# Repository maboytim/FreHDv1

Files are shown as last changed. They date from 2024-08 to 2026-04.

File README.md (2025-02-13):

# TRS-HARD disk emulator, aka 'FreHD'

This is a fork of the original FreHD project by Frederic Vecoven.  The original FreHD project can be found on Frederic's site [https://www.vecoven.com/trs80/trs80.html](https://www.vecoven.com/trs80/trs80.html).  The project has since been moved to github at [https://github.com/veco/FreHDv1](https://github.com/veco/FreHDv1) where the latest versions of everything can be found.

The FreHD emulates both the harddisk controller and the disk storage, plus adds many feature which enhance usability.  The FreHD emulates the original TRS-80 harddisk systems such that the original DOS's that supported hardisks should also work with the FreHD using their original harddisk drivers.

The FreHD consists of several components and the scope of the project is really quite amazing.  First there is hardware itself, which uses a PIC microcontroller for a majority of the function, an SD card for the actual storage, a PAL (programmable logic) for miscellaneous logic, and an RTC (realtime clock).  Software (firmware) embedded in the PIC emulates the harddrive and the additional features and provides access to the RTC.  The main purpose of this fork is to provide compatible alternative firmwares, although it goes a bit beyond that.  Although the intent isn't to improve the original project, some improvements and bugfixes have been provided back to the original project.

The equivalent of everything in the original project is included here but might be modified or improved.     My goal is to maintain as much similarity as possible to the original project including the directory structure.  The directory structure is as follows:

+ hw : Hardware files.
  - gal : Equations of the GAL and the compiled jedec file.
  - protel99 : PCB source (schematics and pcb), in Protel99 format for the original PCB design.  Since it is unlikely that anyone is using Protel99 nowadays this is unlikely to change.
  - kicad : PCB source (schematics and pcb), in KiCad format.  This was converted from the original Protel99 design using a conversion script.  It has since been slightly modified and is subject to change.

+ sw : Software files.
  - pic : PIC MPLAB/MPLABX project files, source code, and compiled hex code.
    - trs_hard : 
    - FatFS  : elm FatFS library, ported to PIC18

+ sw/z80
  - fredhd_rom : source code of the boot menu
  - fredhd_rom/rom-patches : patches for all TRS80 models
  - utils : FreHD utilities

To build the PIC software, you will need Microchip C18 compiler (free)
and MPLab (I used version 8.36). You will also need perl, which is
used to compute the CRC16 used by the bootloader. (If you modify the
source, you need to compile twice, the second time to include the
correct CRC in your hex file).

To build the Z80 code, you need zmac. We are using version 1.3, this
assembler is public domain (by Bruce Norskog and others).

To build the rom patches, you need 'asl'. It is available at:
http://john.ccac.rwth-aachen.de:8000/as/

This project started during the long evenings of December 2012, and I
am very proud to release it to the community today, May 12th 2013. 
Many thanks to Andrew Quinn, who beta-tested and motivated me to
finish this project, or at least make it usable :)

One last thing : you may modify, duplicate, enhance or do whatever you
want with the code. All I ask is to keep this README file. You must
make your modifications available (GPL). If you decide to build and
sell (modified) emulators, all I ask is an emulator for my TRS80, so I
can test your changes.

Enjoy !

-Frederic Vecoven (frederic@vecoven.com)

Last update: Thu Jan 23 15:19:26 2014

!!! github !!!
The code is now available on github. I don't have time to
update/polish the code, so contributions are very welcome.

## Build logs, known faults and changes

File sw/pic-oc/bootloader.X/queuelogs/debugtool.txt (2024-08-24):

2493 1724344660412 GEN4_TO_CONTROLLER_LOG:GEN4_DEBUG_INT_LOG_PIC18F47Q83 Pre:DebugReadTargetMemory
2493 1724344660412 GEN4_TO_CONTROLLER_LOG:GEN4_DEBUG_INT_LOG_PIC18F47Q83 Payload
2493 1724344660412 GEN4_TO_CONTROLLER_LOG:GEN4_DEBUG_INT_LOG_PIC18F47Q83 FileRegs
2493 1724344660412 GEN4_TO_CONTROLLER_LOG:GEN4_DEBUG_INT_LOG_PIC18F47Q83 4d8
2493 1724344660412 GEN4_TO_CONTROLLER_LOG:GEN4_DEBUG_INT_LOG_PIC18F47Q83 4d8
2493 1724344660412 GEN4_TO_CONTROLLER_LOG:GEN4_DEBUG_INT_LOG_PIC18F47Q83 Length = 1
2493 1724344660412 GEN4_TO_CONTROLLER_LOG:GEN4_DEBUG_INT_LOG_PIC18F47Q83 Payload End
2493 1724344660412 XXXX 1724344660412, Thread 2493: XXXX 1724344660412, Entering Thread 2493: Commands::runScriptWithUpload, script name = ReadRAM  
2493 1724344660413 XXXX 1724344660413, Thread 2493: XXXX 1724344660413, Entering Thread 2493: ToolCommUsb::readTransfer, sideData is 0x25 bytes long, transferDataLength is 0x1 bytes long  
2493 1724344660415 XXXX 1724344660415, Thread 2493: com.Send returned false 
2493 1724344660415 XXXX 1724344660415, Thread 2493: readTransfer: exception after writeHeaderAndGetAck null 
2493 1724344660415 XXXX 1724344660415, Thread 2493: XXXX 1724344660415, Entering Thread 2493: ToolCommUsb::recoverFromProtocolError, type = NO_SCRIPT  
2493 1724344660415 XXXX 1724344660415, Thread 2493: Send Abort Script Engine Command 
2493 1724344660415 XXXX 1724344660415, Thread 2493: XXXX 1724344660415, Entering Thread 2493: ToolCommUsb::killScriptEngine  
2493 1724344660417 XXXX 1724344660417, Thread 2493: com.Send returned false 
2493 1724344660417 XXXX 1724344660417, Thread 2493: Failed sending Abort Script Engine Command. Set nuclear option = true 
2493 1724344660417 XXXX 1724344660417, Thread 2493: About to nuke 
2493 1724344660417 XXXX 1724344660417, Thread 2493: XXXX 1724344660417, Entering Thread 2493: ToolCommUsb::nuclearOption  
2493 1724344660419 XXXX 1724344660419, Thread 2493: com.Send returned false

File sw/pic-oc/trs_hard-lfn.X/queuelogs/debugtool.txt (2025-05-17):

2483 1747105636176 GEN4_CONNECT_DIAGNOSTICS:MPLABCommTool is null

2483 1747105636176 GEN4_TO_CONTROLLER_LOG:GEN4_CONNECT_INT_LOG_PIC18F47Q83 Pre:GetFirmwareInfo
2483 1747105636176 GEN4_TO_CONTROLLER_LOG:GEN4_CONNECT_INT_LOG_PIC18F47Q83 Payload
2483 1747105636176 GEN4_TO_CONTROLLER_LOG:GEN4_CONNECT_INT_LOG_PIC18F47Q83 null
2483 1747105636176 GEN4_TO_CONTROLLER_LOG:GEN4_CONNECT_INT_LOG_PIC18F47Q83 Payload End
2483 1747105636177 XXXX 1747105636177, Thread 2483: com.Send returned false 
2483 1747105636177 XXXX 1747105636177, Thread 2483: execCommand: exception after writeSideChanel null 
2483 1747105636177 GEN4_CONNECT_DIAGNOSTICS:Removing plug and play observer com.microchip.mplab.mdbcore.RI4Tool.RI4ToolBase$RI4PlugNPlayObserver@bf5e00b
2483 1747105636177 GEN4_CONNECT_DIAGNOSTICS:Begin PlugNPlayObservers list dump:
2483 1747105636177 GEN4_CONNECT_DIAGNOSTICS:End PlugNPlayObservers list dump:
2483 1747105636228 GEN4_CONNECT_DIAGNOSTICS:Calling RIDbgToolCom.Disconnect
2483 1747105636228 GEN4_CONNECT_DIAGNOSTICS:Calling MPLABCommTool.Detach to remove tool from plug and play list
2483 1747105636228 GEN4_CONNECT_DIAGNOSTICS:Calling RIDbgToolCom.DisconnectFromMPlabComm
2483 1747105636228 GEN4_CONNECT_DIAGNOSTICS:Calling MPLABCommTool.Disconnect
2491 1747105745831 GEN4_CONNECT_DIAGNOSTICS:MPLABCommTool is NOT null
2491 1747105745831 GEN4_CONNECT_DIAGNOSTICS:AttachedToolPID = 9036, AttachedToolVID = 4d8
2491 1747105745831 GEN4_CONNECT_DIAGNOSTICS:transport type = USB
2491 1747105745831 GEN4_CONNECT_DIAGNOSTICS:AttachedToolPID = 9036, AttachedToolVID = 4d8
2491 1747105745834 com.microchip.mplab.mdbcore.RealICETool.RIDbgToolCom
2491 1747105745834 GEN4_CONNECT_DIAGNOSTICS:Before MPLABCommTool.Connect()
2491 1747105745834 GEN4_CONNECT_DIAGNOSTICS:After MPLABCommTool.Connect()
2491 1747105745834 GEN4_CONNECT_DIAGNOSTICS:Adding new plug and play observer com.microchip.mplab.mdbcore.RI4Tool.RI4ToolBase$RI4PlugNPlayObserver@5f161bb
2491 1747105745834 GEN4_CONNECT_DIAGNOSTICS:Begin PlugNPlayObservers list dump:
2491 1747105745834 GEN4_CONNECT_DIAGNOSTICS:com.microchip.mplab.mdbcore.RI4Tool.RI4ToolBase$RI4PlugNPlayObserver@5f161bb
2491 1747105745834 GEN4_CONNECT_DIAGNOSTICS:End PlugNPlayObservers list dump:
2491 1747105745834 GEN4_CONNECT_DIAGNOSTICS:Registering for alternate PNP notifications. CommPnPCriteria.cPIDList = [9035], CommPnPCriteria.cSerialNumber = 020026702ryn015334

2491 1747105745893 GEN4_TO_CONTROLLER_LOG:GEN4_INIT_INT_LOG_PIC18F47Q83 Pre:init
2491 1747105745893 GEN4_TO_CONTROLLER_LOG:GEN4_INIT_INT_LOG_PIC18F47Q83 Payload
2491 1747105745893 GEN4_TO_CONTROLLER_LOG:GEN4_INIT_INT_LOG_PIC18F47Q83 DeviceInfo: Values:
2491 1747105745893 GEN4_TO_CONTROLLER_LOG:GEN4_INIT_INT_LOG_PIC18F47Q83 DeviceInfo: pcAddress = 000004f9, Vpp = 9.00, useRowEraseIfVoltageIsLow = true, voltageBelowWhichUseRowErase = 2.10, deviceName = PIC18F47Q83, programmerType = PIC18ENH_V2
2491 1747105745893 GEN4_TO_CONTROLLER_LOG:GEN4_INIT_INT_LOG_PIC18F47Q83 DeviceInfo: MemInfo values:
2491 1747105745893 GEN4_TO_CONTROLLER_LOG:GEN4_INIT_INT_LOG_PIC18F47Q83 DeviceInfo: mask = ffff, exists = true, startAddr = 00000000, endAddr = 0001ffff, rowSize = 0080, rowEraseSize = 0080, addrInc = 0002, widthProgram = 0002
2491 1747105745893 GEN4_TO_CONTROLLER_LOG:GEN4_INIT_INT_LOG_PIC18F47Q83 DeviceInfo: mask = 00ff, exists = true, startAddr = 00300000, endAddr = 00300023, rowSize = 0001, rowEraseSize = 0000, addrInc = 0001, widthProgram = 0001
2491 1747105745893 GEN4_TO_CONTROLLER_LOG:GEN4_INIT_INT_LOG_PIC18F47Q83 DeviceInfo: mask = 0000, exists = false, startAddr = 00000000, endAddr = 00000000, rowSize = 0000, rowEraseSize = 0000, addrInc = 0000, widthProgram = 0000
2491 1747105745893 GEN4_TO_CONTROLLER_LOG:GEN4_INIT_INT_LOG_PIC18F47Q83 DeviceInfo: mask = 00ff, exists = true, startAddr = 00380000, endAddr = 003803ff, rowSize = 0001, rowEraseSize = 0000, addrInc = 0001, widthProgram = 0001
2491 1747105745893 GEN4_TO_CONTROLLER_LOG:GEN4_INIT_INT_LOG_PIC18F47Q83 DeviceInfo: mask = ffff, exists = true, startAddr = 00200000, endAddr = 0020003f, rowSize = 0001, rowEraseSize = 0000, addrInc = 0002, widthProgram = 0002
2491 1747105745893 GEN4_TO_CONTROLLER_LOG:GEN4_INIT_INT_LOG_PIC18F47Q83 DeviceInfo: mask = ffff, exists = true, startAddr = 00200000, endAddr = 002403ff, rowSize = 0080, rowEraseSize = 0080, addrInc = 0002, widthProgram = 0002
2491 1747105745893 GEN4_TO_CONTROLLER_LOG:GEN4_INIT_INT_LOG_PIC18F47Q83 DeviceInfo: mask = 0000, exists = false, startAddr = 00000000, endAddr = 00000000, rowSize = 0000, rowEraseSize = 0000, addrInc = 0001, widthProgram = 0001
2491 1747105745893 GEN4_TO_CONTROLLER_LOG:GEN4_INIT_INT_LOG_PIC18F47Q83 DeviceInfo: mask = 0000, exists = false, startAddr = 00000000, endAddr = 00000000, rowSize = 0000, rowEraseSize = 0000, addrInc = 0000, widthProgram = 0000
2491 1747105745893 GEN4_TO_CONTROLLER_LOG:GEN4_INIT_INT_LOG_PIC18F47Q83 DeviceInfo: mask = 0000, exists = false, startAddr = 00000000, endAddr = 00000000, rowSize = 0000, rowEraseSize = 0000, addrInc = 0000, widthProgram = 0000
2491 1747105745893 GEN4_TO_CONTROLLER_LOG:GEN4_INIT_INT_LOG_PIC18F47Q83 DeviceInfo: mask = 0000, exists = false, startAddr = 00000000, endAddr = 00000000, rowSize = 0000, rowEraseSize = 0000, addrInc = 0000, widthProgram = 0000
2491 1747105745893 GEN4_TO_CONTROLLER_LOG:GEN4_INIT_INT_LOG_PIC18F47Q83 DeviceInfo: mask = 0000, exists = false, startAddr = 00000000, endAddr = 00000000, rowSize = 0000, rowEraseSize = 0000, addrInc = 0001, widthProgram = 0001
2491 1747105745893 GEN4_TO_CONTROLLER_LOG:GEN4_INIT_INT_LOG_PIC18F47Q83 DeviceInfo: mask = 0000, exists = false, startAddr = 00000000, endAddr = 00000000, rowSize = 0000, rowEraseSize = 0000, addrInc = 0001, widthProgram = 0001
2491 1747105745893 GEN4_TO_CONTROLLER_LOG:GEN4_INIT_INT_LOG_PIC18F47Q83 DeviceInfo: mask = 0000, exists = false, startAddr = 00000000, endAddr = 00000000, rowSize = 0000, rowEraseSize = 0000, addrInc = 0000, widthProgram = 0000
2491 1747105745893 GEN4_TO_CONTROLLER_LOG:GEN4_INIT_INT_LOG_PIC18F47Q83 DeviceInfo: mask = 0000, exists = false, startAddr = 00000000, endAddr = 00000000, rowSize = 0000, rowEraseSize = 0000, addrInc = 0000, widthProgram = 0000
2491 1747105745893 GEN4_TO_CONTROLLER_LOG:GEN4_INIT_INT_LOG_PIC18F47Q83 DeviceInfo: mask = 0000, exists = false, startAddr = 00000000, endAddr = 00000000, rowSize = 0000, rowEraseSize = 0000, addrInc = 0000, widthProgram = 0000
2491 1747105745893 GEN4_TO_CONTROLLER_LOG:GEN4_INIT_INT_LOG_PIC18F47Q83 DeviceInfo: mask = 0000, exists = false, startAddr = 00000000, endAddr = 00000000, rowSize = 0000, rowEraseSize = 0000, addrInc = 0000, widthProgram = 0000
2491 1747105745893 GEN4_TO_CONTROLLER_LOG:GEN4_INIT_INT_LOG_PIC18F47Q83 DeviceInfo: mask = 7fffffff, exists = true, startAddr = 003ffffe, endAddr = 003fffff, rowSize = 0001, rowEraseSize = 0000, addrInc = 0001, widthProgram = 0001
2491 1747105745893 GEN4_TO_CONTROLLER_LOG:GEN4_INIT_INT_LOG_PIC18F47Q83 DeviceInfo: mask = 0000, exists = false, startAddr = 00000000, endAddr = 00000000, rowSize = 0000, rowEraseSize = 0000, addrInc = 0000, widthProgram = 0000
2491 1747105745893 GEN4_TO_CONTROLLER_LOG:GEN4_INIT_INT_LOG_PIC18F47Q83 DeviceInfo: mask = ffff, exists = true, startAddr = 003c0000, endAddr = 003c000f, rowSize = 0080, rowEraseSize = 0000, addrInc = 0002, widthProgram = 0002
2491 1747105745893 GEN4_TO_CONTROLLER_LOG:GEN4_INIT_INT_LOG_PIC18F47Q83 DeviceInfo: mask = ffff, exists = true, startAddr = 002c0000, endAddr = 002c003f, rowSize = 0080, rowEraseSize = 0000, addrInc = 0002, widthProgram = 0002
2491 1747105745893 GEN4_TO_CONTROLLER_LOG:GEN4_INIT_INT_LOG_PIC18F47Q83 DeviceInfo: mask = 0000, exists = false, startAddr = 00000000, endAddr = 00000000, rowSize = 0000, rowEraseSize = 0000, addrInc = 0000, widthProgram = 0000
2491 1747105745893 GEN4_TO_CONTROLLER_LOG:GEN4_INIT_INT_LOG_PIC18F47Q83 DeviceInfo: mask = 0000, exists = false, startAddr = 00000000, endAddr = 00000000, rowSize = 0000, rowEraseSize = 0000, addrInc = 0000, widthProgram = 0000
2491 1747105745893 GEN4_TO_CONTROLLER_LOG:GEN4_INIT_INT_LOG_PIC18F47Q83 DeviceInfo: mask = 0000, exists = false, startAddr = 00000000, endAddr = 00000000, rowSize = 0000, rowEraseSize = 0000, addrInc = 0000, widthProgram = 0000
2491 1747105745893 GEN4_TO_CONTROLLER_LOG:GEN4_INIT_INT_LOG_PIC18F47Q83 DeviceInfo: CfgRequiredBitsMask Values:
2491 1747105745893 GEN4_TO_CONTROLLER_LOG:GEN4_INIT_INT_LOG_PIC18F47Q83 Address = 00300000, Mask = 00000077
2491 1747105745893 GEN4_TO_CONTROLLER_LOG:GEN4_INIT_INT_LOG_PIC18F47Q83 Address = 00300001, Mask = 0000002b
2491 1747105745893 GEN4_TO_CONTROLLER_LOG:GEN4_INIT_INT_LOG_PIC18F47Q83 Address = 00300002, Mask = 000000ff
2491 1747105745893 GEN4_TO_CONTROLLER_LOG:GEN4_INIT_INT_LOG_PIC18F47Q83 Address = 00300003, Mask = 000000bf
2491 1747105745893 GEN4_TO_CONTROLLER_LOG:GEN4_INIT_INT_LOG_PIC18F47Q83 Address = 00300004, Mask = 0000007f
2491 1747105745893 GEN4_TO_CONTROLLER_LOG:GEN4_INIT_INT_LOG_PIC18F47Q83 Address = 00300005, Mask = 0000003f
2491 1747105745893 GEN4_TO_CONTROLLER_LOG:GEN4_INIT_INT_LOG_PIC18F47Q83 Address = 00300006, Mask = 0000001f
2491 1747105745893 GEN4_TO_CONTROLLER_LOG:GEN4_INIT_INT_LOG_PIC18F47Q83 Address = 00300007, Mask = 0000008f
2491 1747105745893 GEN4_TO_CONTROLLER_LOG:GEN4_INIT_INT_LOG_PIC18F47Q83 Address = 00300008, Mask = 00000033
2491 1747105745893 GEN4_TO_CONTROLLER_LOG:GEN4_INIT_INT_LOG_PIC18F47Q83 Address = 00300009, Mask = 00000001
2491 1747105745893 GEN4_TO_CONTROLLER_LOG:GEN4_INIT_INT_LOG_PIC18F47Q83 Address = 0030000a, Mask = 000000ff
2491 1747105745893 GEN4_TO_CONTROLLER_LOG:GEN4_INIT_INT_LOG_PIC18F47Q83 Address = 0030000b, Mask = 000000ff
2491 1747105745893 GEN4_TO_CONTROLLER_LOG:GEN4_INIT_INT_LOG_PIC18F47Q83 Address = 0030000c, Mask = 000000ff
2491 1747105745893 GEN4_TO_CONTROLLER_LOG:GEN4_INIT_INT_LOG_PIC18F47Q83 Address = 0030000d, Mask = 000000ff
2491 1747105745893 GEN4_TO_CONTROLLER_LOG:GEN4_INIT_INT_LOG_PIC18F47Q83 Address = 0030000e, Mask = 000000ff
2491 1747105745893 GEN4_TO_CONTROLLER_LOG:GEN4_INIT_INT_LOG_PIC18F47Q83 Address = 0030000f, Mask = 000000ff
2491 1747105745893 GEN4_TO_CONTROLLER_LOG:GEN4_INIT_INT_LOG_PIC18F47Q83 Address = 00300010, Mask = 000000ff
2491 1747105745893 GEN4_TO_CONTROLLER_LOG:GEN4_INIT_INT_LOG_PIC18F47Q83 Address = 00300011, Mask = 000000ff
2491 1747105745893 GEN4_TO_CONTROLLER_LOG:GEN4_INIT_INT_LOG_PIC18F47Q83 Address = 00300012, Mask = 000000ff
2491 1747105745893 GEN4_TO_CONTROLLER_LOG:GEN4_INIT_INT_LOG_PIC18F47Q83 Address = 00300013, Mask = 000000ff
2491 1747105745893 GEN4_TO_CONTROLLER_LOG:GEN4_INIT_INT_LOG_PIC18F47Q83 Address = 00300014, Mask = 000000ff
2491 1747105745893 GEN4_TO_CONTROLLER_LOG:GEN4_INIT_INT_LOG_PIC18F47Q83 Address = 00300015, Mask = 000000ff
2491 1747105745893 GEN4_TO_CONTROLLER_LOG:GEN4_INIT_INT_LOG_PIC18F47Q83 Address = 00300016, Mask = 000000ff
2491 1747105745893 GEN4_TO_CONTROLLER_LOG:GEN4_INIT_INT_LOG_PIC18F47Q83 Address = 00300017, Mask = 000000ff
2491 1747105745893 GEN4_TO_CONTROLLER_LOG:GEN4_INIT_INT_LOG_PIC18F47Q83 Address = 00300018, Mask = 000000ff
2491 1747105745893 GEN4_TO_CONTROLLER_LOG:GEN4_INIT_INT_LOG_PIC18F47Q83 Address = 00300019, Mask = 000000ff
2491 1747105745893 GEN4_TO_CONTROLLER_LOG:GEN4_INIT_INT_LOG_PIC18F47Q83 Address = 0030001a, Mask = 000000ff
2491 1747105745893 GEN4_TO_CONTROLLER_LOG:GEN4_INIT_INT_LOG_PIC18F47Q83 Address = 0030001b, Mask = 000000ff
2491 1747105745893 GEN4_TO_CONTROLLER_LOG:GEN4_INIT_INT_LOG_PIC18F47Q83 Address = 0030001c, Mask = 000000ff
2491 1747105745893 GEN4_TO_CONTROLLER_LOG:GEN4_INIT_INT_LOG_PIC18F47Q83 Address = 0030001d, Mask = 000000ff
2491 1747105745893 GEN4_TO_CONTROLLER_LOG:GEN4_INIT_INT_LOG_PIC18F47Q83 Address = 0030001e, Mask = 000000ff
2491 1747105745893 GEN4_TO_CONTROLLER_LOG:GEN4_INIT_INT_LOG_PIC18F47Q83 Address = 0030001f, Mask = 000000ff
2491 1747105745893 GEN4_TO_CONTROLLER_LOG:GEN4_INIT_INT_LOG_PIC18F47Q83 Address = 00300020, Mask = 000000ff
2491 1747105745893 GEN4_TO_CONTROLLER_LOG:GEN4_INIT_INT_LOG_PIC18F47Q83 Address = 00300021, Mask = 000000ff
2491 1747105745893 GEN4_TO_CONTROLLER_LOG:GEN4_INIT_INT_LOG_PIC18F47Q83 Address = 00300022, Mask = 000000ff
2491 1747105745893 GEN4_TO_CONTROLLER_LOG:GEN4_INIT_INT_LOG_PIC18F47Q83 BasicInfo: Values:
2491 1747105745893 GEN4_TO_CONTROLLER_LOG:GEN4_INIT_INT_LOG_PIC18F47Q83 BasicInfo: InputStream = com.microchip.mplab.libs.toolpacksupport.EquatableFileInputStream@cc306916, ToolFlavor = PIC32C
2491 1747105745893 GEN4_TO_CONTROLLER_LOG:GEN4_INIT_INT_LOG_PIC18F47Q83 Payload End
2491 1747105745894 GEN4_TO_CONTROLLER_LOG:GEN4_INIT_INT_LOG_PIC18F47Q83 Post:init
2491 1747105745894 GEN4_TO_CONTROLLER_LOG:GEN4_INIT_INT_LOG_PIC18F47Q83 Return Value
2491 1747105745894 GEN4_TO_CONTROLLER_LOG:GEN4_INIT_INT_LOG_PIC18F47Q83 none
2491 1747105745894 GEN4_TO_CONTROLLER_LOG:GEN4_INIT_INT_LOG_PIC18F47Q83 Return End

2491 1747105745894 GEN4_TO_CONTROLLER_LOG:GEN4_INIT_INT_LOG_PIC18F47Q83 Pre:GetInterfaceProvider
2491 1747105745894 GEN4_TO_CONTROLLER_LOG:GEN4_INIT_INT_LOG_PIC18F47Q83 Payload
2491 1747105745894 GEN4_TO_CONTROLLER_LOG:GEN4_INIT_INT_LOG_PIC18F47Q83 RI4DebugInterface
2491 1747105745894 GEN4_TO_CONTROLLER_LOG:GEN4_INIT_INT_LOG_PIC18F47Q83 Payload End
2491 1747105745894 GEN4_TO_CONTROLLER_LOG:GEN4_INIT_INT_LOG_PIC18F47Q83 Post:GetInterfaceProvider
2491 1747105745894 GEN4_TO_CONTROLLER_LOG:GEN4_INIT_INT_LOG_PIC18F47Q83 Return Value
2491 1747105745894 GEN4_TO_CONTROLLER_LOG:GEN4_INIT_INT_LOG_PIC18F47Q83 com.microchip.mplab.libs.RI4ToolsController.implementations.RI4DebugInterfaceImpl@34bef190
2491 1747105745894 GEN4_TO_CONTROLLER_LOG:GEN4_INIT_INT_LOG_PIC18F47Q83 Return End

2491 1747105745895 GEN4_TO_CONTROLLER_LOG:GEN4_INIT_INT_LOG_PIC18F47Q83 Pre:GetInterfaceProvider
2491 1747105745895 GEN4_TO_CONTROLLER_LOG:GEN4_INIT_INT_LOG_PIC18F47Q83 Payload
2491 1747105745895 GEN4_TO_CONTROLLER_LOG:GEN4_INIT_INT_LOG_PIC18F47Q83 RI4ProgramInterface
2491 1747105745895 GEN4_TO_CONTROLLER_LOG:GEN4_INIT_INT_LOG_PIC18F47Q83 Payload End
2491 1747105745895 GEN4_TO_CONTROLLER_LOG:GEN4_INIT_INT_LOG_PIC18F47Q83 Post:GetInterfaceProvider
2491 1747105745895 GEN4_TO_CONTROLLER_LOG:GEN4_INIT_INT_LOG_PIC18F47Q83 Return Value
2491 1747105745895 GEN4_TO_CONTROLLER_LOG:GEN4_INIT_INT_LOG_PIC18F47Q83 com.microchip.mplab.libs.RI4ToolsController.implementations.RI4ProgramInterfaceImpl@10871a2b
2491 1747105745895 GEN4_TO_CONTROLLER_LOG:GEN4_INIT_INT_LOG_PIC18F47Q83 Return End

2491 1747105745895 GEN4_TO_CONTROLLER_LOG:GEN4_INIT_INT_LOG_PIC18F47Q83 Pre:GetInterfaceProvider
2491 1747105745895 GEN4_TO_CONTROLLER_LOG:GEN4_INIT_INT_LOG_PIC18F47Q83 Payload
2491 1747105745895 GEN4_TO_CONTROLLER_LOG:GEN4_INIT_INT_LOG_PIC18F47Q83 RI4ConnectInterface
2491 1747105745895 GEN4_TO_CONTROLLER_LOG:GEN4_INIT_INT_LOG_PIC18F47Q83 Payload End
2491 1747105745895 GEN4_TO_CONTROLLER_LOG:GEN4_INIT_INT_LOG_PIC18F47Q83 Post:GetInterfaceProvider
2491 1747105745895 GEN4_TO_CONTROLLER_LOG:GEN4_INIT_INT_LOG_PIC18F47Q83 Return Value
2491 1747105745895 GEN4_TO_CONTROLLER_LOG:GEN4_INIT_INT_LOG_PIC18F47Q83 com.microchip.mplab.libs.PK4ToolsController.PK4ConnectInterfaceImpl@1ef54d39
2491 1747105745895 GEN4_TO_CONTROLLER_LOG:GEN4_INIT_INT_LOG_PIC18F47Q83 Return End

2491 1747105745895 GEN4_TO_CONTROLLER_LOG:GEN4_INIT_INT_LOG_PIC18F47Q83 Pre:GetInterfaceProvider
2491 1747105745895 GEN4_TO_CONTROLLER_LOG:GEN4_INIT_INT_LOG_PIC18F47Q83 Payload
2491 1747105745895 GEN4_TO_CONTROLLER_LOG:GEN4_INIT_INT_LOG_PIC18F47Q83 RI4ControllerDiagnosticsInterface
2491 1747105745895 GEN4_TO_CONTROLLER_LOG:GEN4_INIT_INT_LOG_PIC18F47Q83 Payload End
2491 1747105745895 GEN4_TO_CONTROLLER_LOG:GEN4_INIT_INT_LOG_PIC18F47Q83 Post:GetInterfaceProvider
2491 1747105745895 GEN4_TO_CONTROLLER_LOG:GEN4_INIT_INT_LOG_PIC18F47Q83 Return Value
2491 1747105745895 GEN4_TO_CONTROLLER_LOG:GEN4_INIT_INT_LOG_PIC18F47Q83 com.microchip.mplab.libs.RI4ToolsController.implementations.RI4ControllerDiagnosticsInterfaceImpl@ddd383b
2491 1747105745895 GEN4_TO_CONTROLLER_LOG:GEN4_INIT_INT_LOG_PIC18F47Q83 Return End

2491 1747105745895 GEN4_TO_CONTROLLER_LOG:GEN4_INIT_INT_LOG_PIC18F47Q83 Pre:GetInterfaceProvider
2491 1747105745895 GEN4_TO_CONTROLLER_LOG:GEN4_INIT_INT_LOG_PIC18F47Q83 Payload
2491 1747105745895 GEN4_TO_CONTROLLER_LOG:GEN4_INIT_INT_LOG_PIC18F47Q83 ProgrammerToGo
2491 1747105745895 GEN4_TO_CONTROLLER_LOG:GEN4_INIT_INT_LOG_PIC18F47Q83 Payload End
2491 1747105745895 GEN4_TO_CONTROLLER_LOG:GEN4_INIT_INT_LOG_PIC18F47Q83 Post:GetInterfaceProvider
2491 1747105745895 GEN4_TO_CONTROLLER_LOG:GEN4_INIT_INT_LOG_PIC18F47Q83 Return Value
2491 1747105745895 GEN4_TO_CONTROLLER_LOG:GEN4_INIT_INT_LOG_PIC18F47Q83 com.microchip.mplab.libs.RI4ToolsController.implementations.ProgrammerToGoImpl@4e2c6a61
2491 1747105745895 GEN4_TO_CONTROLLER_LOG:GEN4_INIT_INT_LOG_PIC18F47Q83 Return End

2491 1747105745895 GEN4_TO_CONTROLLER_LOG:GEN4_INIT_INT_LOG_PIC18F47Q83 Pre:GetInterfaceProvider
2491 1747105745895 GEN4_TO_CONTROLLER_LOG:GEN4_INIT_INT_LOG_PIC18F47Q83 Payload
2491 1747105745895 GEN4_TO_CONTROLLER_LOG:GEN4_INIT_INT_LOG_PIC18F47Q83 Status
2491 1747105745895 GEN4_TO_CONTROLLER_LOG:GEN4_INIT_INT_LOG_PIC18F47Q83 Payload End
2491 1747105745895 GEN4_TO_CONTROLLER_LOG:GEN4_INIT_INT_LOG_PIC18F47Q83 Post:GetInterfaceProvider
2491 1747105745895 GEN4_TO_CONTROLLER_LOG:GEN4_INIT_INT_LOG_PIC18F47Q83 Return Value
2491 1747105745895 GEN4_TO_CONTROLLER_LOG:GEN4_INIT_INT_LOG_PIC18F47Q83 null
2491 1747105745895 GEN4_TO_CONTROLLER_LOG:GEN4_INIT_INT_LOG_PIC18F47Q83 Return End

2491 1747105745900 GEN4_TO_CONTROLLER_LOG:GEN4_CONNECT_INT_LOG_PIC18F47Q83 Pre:EstablishCommunincations
2491 1747105745900 GEN4_TO_CONTROLLER_LOG:GEN4_CONNECT_INT_LOG_PIC18F47Q83 Payload
2491 1747105745900 GEN4_TO_CONTROLLER_LOG:GEN4_CONNECT_INT_LOG_PIC18F47Q83 com.microchip.mplab.mdbcore.PK5Tool.PK5Com@581f905c
2491 1747105745900 GEN4_TO_CONTROLLER_LOG:GEN4_CONNECT_INT_LOG_PIC18F47Q83 Payload End
2491 1747105745900 GEN4_TO_CONTROLLER_LOG:GEN4_CONNECT_INT_LOG_PIC18F47Q83 Post:EstablishCommunincations
2491 1747105745900 GEN4_TO_CONTROLLER_LOG:GEN4_CONNECT_INT_LOG_PIC18F47Q83 Return Value
2491 1747105745900 GEN4_TO_CONTROLLER_LOG:GEN4_CONNECT_INT_LOG_PIC18F47Q83 true
2491 1747105745900 GEN4_TO_CONTROLLER_LOG:GEN4_CONNECT_INT_LOG_PIC18F47Q83 Return End

2491 1747105745900 GEN4_TO_CONTROLLER_LOG:GEN4_CONNECT_INT_LOG_PIC18F47Q83 Pre:GetFirmwareInfo
2491 1747105745900 GEN4_TO_CONTROLLER_LOG:GEN4_CONNECT_INT_LOG_PIC18F47Q83 Payload
2491 1747105745900 GEN4_TO_CONTROLLER_LOG:GEN4_CONNECT_INT_LOG_PIC18F47Q83 null
2491 1747105745900 GEN4_TO_CONTROLLER_LOG:GEN4_CONNECT_INT_LOG_PIC18F47Q83 Payload End
2491 1747105745902 XXXX 1747105745902, Thread 2491: com.Send returned false 
2491 1747105745902 XXXX 1747105745902, Thread 2491: execCommand: exception after writeSideChanel null

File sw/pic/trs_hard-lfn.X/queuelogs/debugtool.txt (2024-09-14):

570 1726315974327 GEN4_CONNECT_DIAGNOSTICS:MPLABCommTool is null

570 1726315974327 GEN4_TO_CONTROLLER_LOG:GEN4_CONNECT_INT_LOG_PIC18F47Q83 Pre:GetFirmwareInfo
570 1726315974327 GEN4_TO_CONTROLLER_LOG:GEN4_CONNECT_INT_LOG_PIC18F47Q83 Payload
570 1726315974327 GEN4_TO_CONTROLLER_LOG:GEN4_CONNECT_INT_LOG_PIC18F47Q83 null
570 1726315974327 GEN4_TO_CONTROLLER_LOG:GEN4_CONNECT_INT_LOG_PIC18F47Q83 Payload End
570 1726315974329 XXXX 1726315974329, Thread 570: com.Send returned false 
570 1726315974329 XXXX 1726315974329, Thread 570: execCommand: exception after writeSideChanel null 
570 1726315974329 GEN4_CONNECT_DIAGNOSTICS:Removing plug and play observer com.microchip.mplab.mdbcore.RI4Tool.RI4ToolBase$RI4PlugNPlayObserver@43e7f41
570 1726315974329 GEN4_CONNECT_DIAGNOSTICS:Begin PlugNPlayObservers list dump:
570 1726315974329 GEN4_CONNECT_DIAGNOSTICS:End PlugNPlayObservers list dump:
570 1726315974380 GEN4_CONNECT_DIAGNOSTICS:Calling RIDbgToolCom.Disconnect
570 1726315974380 GEN4_CONNECT_DIAGNOSTICS:Calling MPLABCommTool.Detach to remove tool from plug and play list
570 1726315974380 GEN4_CONNECT_DIAGNOSTICS:Calling RIDbgToolCom.DisconnectFromMPlabComm
570 1726315974380 GEN4_CONNECT_DIAGNOSTICS:Calling MPLABCommTool.Disconnect
578 1726315976465 GEN4_CONNECT_DIAGNOSTICS:MPLABCommTool is NOT null
578 1726315976465 GEN4_CONNECT_DIAGNOSTICS:AttachedToolPID = 9036, AttachedToolVID = 4d8
578 1726315976465 GEN4_CONNECT_DIAGNOSTICS:transport type = USB
578 1726315976465 GEN4_CONNECT_DIAGNOSTICS:AttachedToolPID = 9036, AttachedToolVID = 4d8
578 1726315976467 com.microchip.mplab.mdbcore.RealICETool.RIDbgToolCom
578 1726315976467 GEN4_CONNECT_DIAGNOSTICS:Before MPLABCommTool.Connect()
578 1726315976467 GEN4_CONNECT_DIAGNOSTICS:After MPLABCommTool.Connect()
578 1726315976467 GEN4_CONNECT_DIAGNOSTICS:Adding new plug and play observer com.microchip.mplab.mdbcore.RI4Tool.RI4ToolBase$RI4PlugNPlayObserver@74fbcd1b
578 1726315976467 GEN4_CONNECT_DIAGNOSTICS:Begin PlugNPlayObservers list dump:
578 1726315976467 GEN4_CONNECT_DIAGNOSTICS:com.microchip.mplab.mdbcore.RI4Tool.RI4ToolBase$RI4PlugNPlayObserver@74fbcd1b
578 1726315976467 GEN4_CONNECT_DIAGNOSTICS:End PlugNPlayObservers list dump:
578 1726315976468 GEN4_CONNECT_DIAGNOSTICS:Registering for alternate PNP notifications. CommPnPCriteria.cPIDList = [9035], CommPnPCriteria.cSerialNumber = 020026702ryn015334

578 1726315976628 GEN4_TO_CONTROLLER_LOG:GEN4_INIT_INT_LOG_PIC18F47Q83 Pre:init
578 1726315976628 GEN4_TO_CONTROLLER_LOG:GEN4_INIT_INT_LOG_PIC18F47Q83 Payload
578 1726315976628 GEN4_TO_CONTROLLER_LOG:GEN4_INIT_INT_LOG_PIC18F47Q83 DeviceInfo: Values:
578 1726315976628 GEN4_TO_CONTROLLER_LOG:GEN4_INIT_INT_LOG_PIC18F47Q83 DeviceInfo: pcAddress = 000004f9, Vpp = 9.00, useRowEraseIfVoltageIsLow = true, voltageBelowWhichUseRowErase = 2.10, deviceName = PIC18F47Q83, programmerType = PIC18ENH_V2
578 1726315976628 GEN4_TO_CONTROLLER_LOG:GEN4_INIT_INT_LOG_PIC18F47Q83 DeviceInfo: MemInfo values:
578 1726315976628 GEN4_TO_CONTROLLER_LOG:GEN4_INIT_INT_LOG_PIC18F47Q83 DeviceInfo: mask = ffff, exists = true, startAddr = 00000000, endAddr = 0001ffff, rowSize = 0080, rowEraseSize = 0080, addrInc = 0002, widthProgram = 0002
578 1726315976628 GEN4_TO_CONTROLLER_LOG:GEN4_INIT_INT_LOG_PIC18F47Q83 DeviceInfo: mask = 00ff, exists = true, startAddr = 00300000, endAddr = 00300023, rowSize = 0001, rowEraseSize = 0000, addrInc = 0001, widthProgram = 0001
578 1726315976628 GEN4_TO_CONTROLLER_LOG:GEN4_INIT_INT_LOG_PIC18F47Q83 DeviceInfo: mask = 0000, exists = false, startAddr = 00000000, endAddr = 00000000, rowSize = 0000, rowEraseSize = 0000, addrInc = 0000, widthProgram = 0000
578 1726315976628 GEN4_TO_CONTROLLER_LOG:GEN4_INIT_INT_LOG_PIC18F47Q83 DeviceInfo: mask = 00ff, exists = true, startAddr = 00380000, endAddr = 003803ff, rowSize = 0001, rowEraseSize = 0000, addrInc = 0001, widthProgram = 0001
578 1726315976628 GEN4_TO_CONTROLLER_LOG:GEN4_INIT_INT_LOG_PIC18F47Q83 DeviceInfo: mask = ffff, exists = true, startAddr = 00200000, endAddr = 0020003f, rowSize = 0001, rowEraseSize = 0000, addrInc = 0002, widthProgram = 0002
578 1726315976628 GEN4_TO_CONTROLLER_LOG:GEN4_INIT_INT_LOG_PIC18F47Q83 DeviceInfo: mask = ffff, exists = true, startAddr = 00200000, endAddr = 002403ff, rowSize = 0080, rowEraseSize = 0080, addrInc = 0002, widthProgram = 0002
578 1726315976628 GEN4_TO_CONTROLLER_LOG:GEN4_INIT_INT_LOG_PIC18F47Q83 DeviceInfo: mask = 0000, exists = false, startAddr = 00000000, endAddr = 00000000, rowSize = 0000, rowEraseSize = 0000, addrInc = 0001, widthProgram = 0001
578 1726315976628 GEN4_TO_CONTROLLER_LOG:GEN4_INIT_INT_LOG_PIC18F47Q83 DeviceInfo: mask = 0000, exists = false, startAddr = 00000000, endAddr = 00000000, rowSize = 0000, rowEraseSize = 0000, addrInc = 0000, widthProgram = 0000
578 1726315976628 GEN4_TO_CONTROLLER_LOG:GEN4_INIT_INT_LOG_PIC18F47Q83 DeviceInfo: mask = 0000, exists = false, startAddr = 00000000, endAddr = 00000000, rowSize = 0000, rowEraseSize = 0000, addrInc = 0000, widthProgram = 0000
578 1726315976628 GEN4_TO_CONTROLLER_LOG:GEN4_INIT_INT_LOG_PIC18F47Q83 DeviceInfo: mask = 0000, exists = false, startAddr = 00000000, endAddr = 00000000, rowSize = 0000, rowEraseSize = 0000, addrInc = 0000, widthProgram = 0000
578 1726315976628 GEN4_TO_CONTROLLER_LOG:GEN4_INIT_INT_LOG_PIC18F47Q83 DeviceInfo: mask = 0000, exists = false, startAddr = 00000000, endAddr = 00000000, rowSize = 0000, rowEraseSize = 0000, addrInc = 0001, widthProgram = 0001
578 1726315976628 GEN4_TO_CONTROLLER_LOG:GEN4_INIT_INT_LOG_PIC18F47Q83 DeviceInfo: mask = 0000, exists = false, startAddr = 00000000, endAddr = 00000000, rowSize = 0000, rowEraseSize = 0000, addrInc = 0001, widthProgram = 0001
578 1726315976628 GEN4_TO_CONTROLLER_LOG:GEN4_INIT_INT_LOG_PIC18F47Q83 DeviceInfo: mask = 0000, exists = false, startAddr = 00000000, endAddr = 00000000, rowSize = 0000, rowEraseSize = 0000, addrInc = 0000, widthProgram = 0000
578 1726315976628 GEN4_TO_CONTROLLER_LOG:GEN4_INIT_INT_LOG_PIC18F47Q83 DeviceInfo: mask = 0000, exists = false, startAddr = 00000000, endAddr = 00000000, rowSize = 0000, rowEraseSize = 0000, addrInc = 0000, widthProgram = 0000
578 1726315976628 GEN4_TO_CONTROLLER_LOG:GEN4_INIT_INT_LOG_PIC18F47Q83 DeviceInfo: mask = 0000, exists = false, startAddr = 00000000, endAddr = 00000000, rowSize = 0000, rowEraseSize = 0000, addrInc = 0000, widthProgram = 0000
578 1726315976628 GEN4_TO_CONTROLLER_LOG:GEN4_INIT_INT_LOG_PIC18F47Q83 DeviceInfo: mask = 0000, exists = false, startAddr = 00000000, endAddr = 00000000, rowSize = 0000, rowEraseSize = 0000, addrInc = 0000, widthProgram = 0000
578 1726315976628 GEN4_TO_CONTROLLER_LOG:GEN4_INIT_INT_LOG_PIC18F47Q83 DeviceInfo: mask = 7fffffff, exists = true, startAddr = 003ffffe, endAddr = 003fffff, rowSize = 0001, rowEraseSize = 0000, addrInc = 0001, widthProgram = 0001
578 1726315976628 GEN4_TO_CONTROLLER_LOG:GEN4_INIT_INT_LOG_PIC18F47Q83 DeviceInfo: mask = 0000, exists = false, startAddr = 00000000, endAddr = 00000000, rowSize = 0000, rowEraseSize = 0000, addrInc = 0000, widthProgram = 0000
578 1726315976628 GEN4_TO_CONTROLLER_LOG:GEN4_INIT_INT_LOG_PIC18F47Q83 DeviceInfo: mask = ffff, exists = true, startAddr = 003c0000, endAddr = 003c000f, rowSize = 0080, rowEraseSize = 0000, addrInc = 0002, widthProgram = 0002
578 1726315976628 GEN4_TO_CONTROLLER_LOG:GEN4_INIT_INT_LOG_PIC18F47Q83 DeviceInfo: mask = ffff, exists = true, startAddr = 002c0000, endAddr = 002c003f, rowSize = 0080, rowEraseSize = 0000, addrInc = 0002, widthProgram = 0002
578 1726315976628 GEN4_TO_CONTROLLER_LOG:GEN4_INIT_INT_LOG_PIC18F47Q83 DeviceInfo: mask = 0000, exists = false, startAddr = 00000000, endAddr = 00000000, rowSize = 0000, rowEraseSize = 0000, addrInc = 0000, widthProgram = 0000
578 1726315976628 GEN4_TO_CONTROLLER_LOG:GEN4_INIT_INT_LOG_PIC18F47Q83 DeviceInfo: mask = 0000, exists = false, startAddr = 00000000, endAddr = 00000000, rowSize = 0000, rowEraseSize = 0000, addrInc = 0000, widthProgram = 0000
578 1726315976628 GEN4_TO_CONTROLLER_LOG:GEN4_INIT_INT_LOG_PIC18F47Q83 DeviceInfo: mask = 0000, exists = false, startAddr = 00000000, endAddr = 00000000, rowSize = 0000, rowEraseSize = 0000, addrInc = 0000, widthProgram = 0000
578 1726315976628 GEN4_TO_CONTROLLER_LOG:GEN4_INIT_INT_LOG_PIC18F47Q83 DeviceInfo: CfgRequiredBitsMask Values:
578 1726315976628 GEN4_TO_CONTROLLER_LOG:GEN4_INIT_INT_LOG_PIC18F47Q83 Address = 00300000, Mask = 00000077
578 1726315976628 GEN4_TO_CONTROLLER_LOG:GEN4_INIT_INT_LOG_PIC18F47Q83 Address = 00300001, Mask = 0000002b
578 1726315976628 GEN4_TO_CONTROLLER_LOG:GEN4_INIT_INT_LOG_PIC18F47Q83 Address = 00300002, Mask = 000000ff
578 1726315976628 GEN4_TO_CONTROLLER_LOG:GEN4_INIT_INT_LOG_PIC18F47Q83 Address = 00300003, Mask = 000000bf
578 1726315976628 GEN4_TO_CONTROLLER_LOG:GEN4_INIT_INT_LOG_PIC18F47Q83 Address = 00300004, Mask = 0000007f
578 1726315976628 GEN4_TO_CONTROLLER_LOG:GEN4_INIT_INT_LOG_PIC18F47Q83 Address = 00300005, Mask = 0000003f
578 1726315976628 GEN4_TO_CONTROLLER_LOG:GEN4_INIT_INT_LOG_PIC18F47Q83 Address = 00300006, Mask = 0000001f
578 1726315976628 GEN4_TO_CONTROLLER_LOG:GEN4_INIT_INT_LOG_PIC18F47Q83 Address = 00300007, Mask = 0000008f
578 1726315976628 GEN4_TO_CONTROLLER_LOG:GEN4_INIT_INT_LOG_PIC18F47Q83 Address = 00300008, Mask = 00000033
578 1726315976628 GEN4_TO_CONTROLLER_LOG:GEN4_INIT_INT_LOG_PIC18F47Q83 Address = 00300009, Mask = 00000001
578 1726315976628 GEN4_TO_CONTROLLER_LOG:GEN4_INIT_INT_LOG_PIC18F47Q83 Address = 0030000a, Mask = 000000ff
578 1726315976628 GEN4_TO_CONTROLLER_LOG:GEN4_INIT_INT_LOG_PIC18F47Q83 Address = 0030000b, Mask = 000000ff
578 1726315976628 GEN4_TO_CONTROLLER_LOG:GEN4_INIT_INT_LOG_PIC18F47Q83 Address = 0030000c, Mask = 000000ff
578 1726315976628 GEN4_TO_CONTROLLER_LOG:GEN4_INIT_INT_LOG_PIC18F47Q83 Address = 0030000d, Mask = 000000ff
578 1726315976628 GEN4_TO_CONTROLLER_LOG:GEN4_INIT_INT_LOG_PIC18F47Q83 Address = 0030000e, Mask = 000000ff
578 1726315976628 GEN4_TO_CONTROLLER_LOG:GEN4_INIT_INT_LOG_PIC18F47Q83 Address = 0030000f, Mask = 000000ff
578 1726315976628 GEN4_TO_CONTROLLER_LOG:GEN4_INIT_INT_LOG_PIC18F47Q83 Address = 00300010, Mask = 000000ff
578 1726315976628 GEN4_TO_CONTROLLER_LOG:GEN4_INIT_INT_LOG_PIC18F47Q83 Address = 00300011, Mask = 000000ff
578 1726315976628 GEN4_TO_CONTROLLER_LOG:GEN4_INIT_INT_LOG_PIC18F47Q83 Address = 00300012, Mask = 000000ff
578 1726315976628 GEN4_TO_CONTROLLER_LOG:GEN4_INIT_INT_LOG_PIC18F47Q83 Address = 00300013, Mask = 000000ff
578 1726315976628 GEN4_TO_CONTROLLER_LOG:GEN4_INIT_INT_LOG_PIC18F47Q83 Address = 00300014, Mask = 000000ff
578 1726315976628 GEN4_TO_CONTROLLER_LOG:GEN4_INIT_INT_LOG_PIC18F47Q83 Address = 00300015, Mask = 000000ff
578 1726315976628 GEN4_TO_CONTROLLER_LOG:GEN4_INIT_INT_LOG_PIC18F47Q83 Address = 00300016, Mask = 000000ff
578 1726315976628 GEN4_TO_CONTROLLER_LOG:GEN4_INIT_INT_LOG_PIC18F47Q83 Address = 00300017, Mask = 000000ff
578 1726315976628 GEN4_TO_CONTROLLER_LOG:GEN4_INIT_INT_LOG_PIC18F47Q83 Address = 00300018, Mask = 000000ff
578 1726315976628 GEN4_TO_CONTROLLER_LOG:GEN4_INIT_INT_LOG_PIC18F47Q83 Address = 00300019, Mask = 000000ff
578 1726315976628 GEN4_TO_CONTROLLER_LOG:GEN4_INIT_INT_LOG_PIC18F47Q83 Address = 0030001a, Mask = 000000ff
578 1726315976628 GEN4_TO_CONTROLLER_LOG:GEN4_INIT_INT_LOG_PIC18F47Q83 Address = 0030001b, Mask = 000000ff
578 1726315976628 GEN4_TO_CONTROLLER_LOG:GEN4_INIT_INT_LOG_PIC18F47Q83 Address = 0030001c, Mask = 000000ff
578 1726315976628 GEN4_TO_CONTROLLER_LOG:GEN4_INIT_INT_LOG_PIC18F47Q83 Address = 0030001d, Mask = 000000ff
578 1726315976628 GEN4_TO_CONTROLLER_LOG:GEN4_INIT_INT_LOG_PIC18F47Q83 Address = 0030001e, Mask = 000000ff
578 1726315976628 GEN4_TO_CONTROLLER_LOG:GEN4_INIT_INT_LOG_PIC18F47Q83 Address = 0030001f, Mask = 000000ff
578 1726315976628 GEN4_TO_CONTROLLER_LOG:GEN4_INIT_INT_LOG_PIC18F47Q83 Address = 00300020, Mask = 000000ff
578 1726315976628 GEN4_TO_CONTROLLER_LOG:GEN4_INIT_INT_LOG_PIC18F47Q83 Address = 00300021, Mask = 000000ff
578 1726315976628 GEN4_TO_CONTROLLER_LOG:GEN4_INIT_INT_LOG_PIC18F47Q83 Address = 00300022, Mask = 000000ff
578 1726315976628 GEN4_TO_CONTROLLER_LOG:GEN4_INIT_INT_LOG_PIC18F47Q83 BasicInfo: Values:
578 1726315976628 GEN4_TO_CONTROLLER_LOG:GEN4_INIT_INT_LOG_PIC18F47Q83 BasicInfo: InputStream = com.microchip.mplab.libs.toolpacksupport.EquatableFileInputStream@cc306916, ToolFlavor = PIC32C
578 1726315976628 GEN4_TO_CONTROLLER_LOG:GEN4_INIT_INT_LOG_PIC18F47Q83 Payload End
578 1726315976628 GEN4_TO_CONTROLLER_LOG:GEN4_INIT_INT_LOG_PIC18F47Q83 Post:init
578 1726315976628 GEN4_TO_CONTROLLER_LOG:GEN4_INIT_INT_LOG_PIC18F47Q83 Return Value
578 1726315976628 GEN4_TO_CONTROLLER_LOG:GEN4_INIT_INT_LOG_PIC18F47Q83 none
578 1726315976628 GEN4_TO_CONTROLLER_LOG:GEN4_INIT_INT_LOG_PIC18F47Q83 Return End

578 1726315976628 GEN4_TO_CONTROLLER_LOG:GEN4_INIT_INT_LOG_PIC18F47Q83 Pre:GetInterfaceProvider
578 1726315976628 GEN4_TO_CONTROLLER_LOG:GEN4_INIT_INT_LOG_PIC18F47Q83 Payload
578 1726315976628 GEN4_TO_CONTROLLER_LOG:GEN4_INIT_INT_LOG_PIC18F47Q83 RI4DebugInterface
578 1726315976628 GEN4_TO_CONTROLLER_LOG:GEN4_INIT_INT_LOG_PIC18F47Q83 Payload End
578 1726315976628 GEN4_TO_CONTROLLER_LOG:GEN4_INIT_INT_LOG_PIC18F47Q83 Post:GetInterfaceProvider
578 1726315976628 GEN4_TO_CONTROLLER_LOG:GEN4_INIT_INT_LOG_PIC18F47Q83 Return Value
578 1726315976628 GEN4_TO_CONTROLLER_LOG:GEN4_INIT_INT_LOG_PIC18F47Q83 com.microchip.mplab.libs.RI4ToolsController.implementations.RI4DebugInterfaceImpl@58aaba05
578 1726315976628 GEN4_TO_CONTROLLER_LOG:GEN4_INIT_INT_LOG_PIC18F47Q83 Return End

578 1726315976629 GEN4_TO_CONTROLLER_LOG:GEN4_INIT_INT_LOG_PIC18F47Q83 Pre:GetInterfaceProvider
578 1726315976629 GEN4_TO_CONTROLLER_LOG:GEN4_INIT_INT_LOG_PIC18F47Q83 Payload
578 1726315976629 GEN4_TO_CONTROLLER_LOG:GEN4_INIT_INT_LOG_PIC18F47Q83 RI4ProgramInterface
578 1726315976629 GEN4_TO_CONTROLLER_LOG:GEN4_INIT_INT_LOG_PIC18F47Q83 Payload End
578 1726315976629 GEN4_TO_CONTROLLER_LOG:GEN4_INIT_INT_LOG_PIC18F47Q83 Post:GetInterfaceProvider
578 1726315976629 GEN4_TO_CONTROLLER_LOG:GEN4_INIT_INT_LOG_PIC18F47Q83 Return Value
578 1726315976629 GEN4_TO_CONTROLLER_LOG:GEN4_INIT_INT_LOG_PIC18F47Q83 com.microchip.mplab.libs.RI4ToolsController.implementations.RI4ProgramInterfaceImpl@45469829
578 1726315976629 GEN4_TO_CONTROLLER_LOG:GEN4_INIT_INT_LOG_PIC18F47Q83 Return End

578 1726315976629 GEN4_TO_CONTROLLER_LOG:GEN4_INIT_INT_LOG_PIC18F47Q83 Pre:GetInterfaceProvider
578 1726315976629 GEN4_TO_CONTROLLER_LOG:GEN4_INIT_INT_LOG_PIC18F47Q83 Payload
578 1726315976629 GEN4_TO_CONTROLLER_LOG:GEN4_INIT_INT_LOG_PIC18F47Q83 RI4ConnectInterface
578 1726315976629 GEN4_TO_CONTROLLER_LOG:GEN4_INIT_INT_LOG_PIC18F47Q83 Payload End
578 1726315976629 GEN4_TO_CONTROLLER_LOG:GEN4_INIT_INT_LOG_PIC18F47Q83 Post:GetInterfaceProvider
578 1726315976629 GEN4_TO_CONTROLLER_LOG:GEN4_INIT_INT_LOG_PIC18F47Q83 Return Value
578 1726315976629 GEN4_TO_CONTROLLER_LOG:GEN4_INIT_INT_LOG_PIC18F47Q83 com.microchip.mplab.libs.PK4ToolsController.PK4ConnectInterfaceImpl@6fff068f
578 1726315976629 GEN4_TO_CONTROLLER_LOG:GEN4_INIT_INT_LOG_PIC18F47Q83 Return End

578 1726315976630 GEN4_TO_CONTROLLER_LOG:GEN4_INIT_INT_LOG_PIC18F47Q83 Pre:GetInterfaceProvider
578 1726315976630 GEN4_TO_CONTROLLER_LOG:GEN4_INIT_INT_LOG_PIC18F47Q83 Payload
578 1726315976630 GEN4_TO_CONTROLLER_LOG:GEN4_INIT_INT_LOG_PIC18F47Q83 RI4ControllerDiagnosticsInterface
578 1726315976630 GEN4_TO_CONTROLLER_LOG:GEN4_INIT_INT_LOG_PIC18F47Q83 Payload End
578 1726315976630 GEN4_TO_CONTROLLER_LOG:GEN4_INIT_INT_LOG_PIC18F47Q83 Post:GetInterfaceProvider
578 1726315976630 GEN4_TO_CONTROLLER_LOG:GEN4_INIT_INT_LOG_PIC18F47Q83 Return Value
578 1726315976630 GEN4_TO_CONTROLLER_LOG:GEN4_INIT_INT_LOG_PIC18F47Q83 com.microchip.mplab.libs.RI4ToolsController.implementations.RI4ControllerDiagnosticsInterfaceImpl@7ac3feb9
578 1726315976630 GEN4_TO_CONTROLLER_LOG:GEN4_INIT_INT_LOG_PIC18F47Q83 Return End

578 1726315976630 GEN4_TO_CONTROLLER_LOG:GEN4_INIT_INT_LOG_PIC18F47Q83 Pre:GetInterfaceProvider
578 1726315976630 GEN4_TO_CONTROLLER_LOG:GEN4_INIT_INT_LOG_PIC18F47Q83 Payload
578 1726315976630 GEN4_TO_CONTROLLER_LOG:GEN4_INIT_INT_LOG_PIC18F47Q83 ProgrammerToGo
578 1726315976630 GEN4_TO_CONTROLLER_LOG:GEN4_INIT_INT_LOG_PIC18F47Q83 Payload End
578 1726315976630 GEN4_TO_CONTROLLER_LOG:GEN4_INIT_INT_LOG_PIC18F47Q83 Post:GetInterfaceProvider
578 1726315976630 GEN4_TO_CONTROLLER_LOG:GEN4_INIT_INT_LOG_PIC18F47Q83 Return Value
578 1726315976630 GEN4_TO_CONTROLLER_LOG:GEN4_INIT_INT_LOG_PIC18F47Q83 com.microchip.mplab.libs.RI4ToolsController.implementations.ProgrammerToGoImpl@77341976
578 1726315976630 GEN4_TO_CONTROLLER_LOG:GEN4_INIT_INT_LOG_PIC18F47Q83 Return End

578 1726315976630 GEN4_TO_CONTROLLER_LOG:GEN4_INIT_INT_LOG_PIC18F47Q83 Pre:GetInterfaceProvider
578 1726315976630 GEN4_TO_CONTROLLER_LOG:GEN4_INIT_INT_LOG_PIC18F47Q83 Payload
578 1726315976630 GEN4_TO_CONTROLLER_LOG:GEN4_INIT_INT_LOG_PIC18F47Q83 Status
578 1726315976630 GEN4_TO_CONTROLLER_LOG:GEN4_INIT_INT_LOG_PIC18F47Q83 Payload End
578 1726315976630 GEN4_TO_CONTROLLER_LOG:GEN4_INIT_INT_LOG_PIC18F47Q83 Post:GetInterfaceProvider
578 1726315976630 GEN4_TO_CONTROLLER_LOG:GEN4_INIT_INT_LOG_PIC18F47Q83 Return Value
578 1726315976630 GEN4_TO_CONTROLLER_LOG:GEN4_INIT_INT_LOG_PIC18F47Q83 null
578 1726315976630 GEN4_TO_CONTROLLER_LOG:GEN4_INIT_INT_LOG_PIC18F47Q83 Return End

578 1726315976703 GEN4_TO_CONTROLLER_LOG:GEN4_PROGRAM_INT_LOG_PIC18F47Q83 Pre:SetDebugExec
578 1726315976703 GEN4_TO_CONTROLLER_LOG:GEN4_PROGRAM_INT_LOG_PIC18F47Q83 Payload
578 1726315976703 GEN4_TO_CONTROLLER_LOG:GEN4_PROGRAM_INT_LOG_PIC18F47Q83 Test
578 1726315976703 GEN4_TO_CONTROLLER_LOG:GEN4_PROGRAM_INT_LOG_PIC18F47Q83 240000
578 1726315976703 GEN4_TO_CONTROLLER_LOG:GEN4_PROGRAM_INT_LOG_PIC18F47Q83 Length = 924
578 1726315976703 GEN4_TO_CONTROLLER_LOG:GEN4_PROGRAM_INT_LOG_PIC18F47Q83 Payload End
578 1726315976703 GEN4_TO_CONTROLLER_LOG:GEN4_PROGRAM_INT_LOG_PIC18F47Q83 Post:SetDebugExec
578 1726315976703 GEN4_TO_CONTROLLER_LOG:GEN4_PROGRAM_INT_LOG_PIC18F47Q83 Return Value
578 1726315976703 GEN4_TO_CONTROLLER_LOG:GEN4_PROGRAM_INT_LOG_PIC18F47Q83 true
578 1726315976703 GEN4_TO_CONTROLLER_LOG:GEN4_PROGRAM_INT_LOG_PIC18F47Q83 Return End

578 1726315976703 GEN4_TO_CONTROLLER_LOG:GEN4_CONNECT_INT_LOG_PIC18F47Q83 Pre:EstablishCommunincations
578 1726315976703 GEN4_TO_CONTROLLER_LOG:GEN4_CONNECT_INT_LOG_PIC18F47Q83 Payload
578 1726315976703 GEN4_TO_CONTROLLER_LOG:GEN4_CONNECT_INT_LOG_PIC18F47Q83 com.microchip.mplab.mdbcore.PK5Tool.PK5Com@2ff640f1
578 1726315976703 GEN4_TO_CONTROLLER_LOG:GEN4_CONNECT_INT_LOG_PIC18F47Q83 Payload End
578 1726315976703 GEN4_TO_CONTROLLER_LOG:GEN4_CONNECT_INT_LOG_PIC18F47Q83 Post:EstablishCommunincations
578 1726315976703 GEN4_TO_CONTROLLER_LOG:GEN4_CONNECT_INT_LOG_PIC18F47Q83 Return Value
578 1726315976703 GEN4_TO_CONTROLLER_LOG:GEN4_CONNECT_INT_LOG_PIC18F47Q83 true
578 1726315976703 GEN4_TO_CONTROLLER_LOG:GEN4_CONNECT_INT_LOG_PIC18F47Q83 Return End

578 1726315976703 GEN4_TO_CONTROLLER_LOG:GEN4_CONNECT_INT_LOG_PIC18F47Q83 Pre:GetFirmwareInfo
578 1726315976703 GEN4_TO_CONTROLLER_LOG:GEN4_CONNECT_INT_LOG_PIC18F47Q83 Payload
578 1726315976703 GEN4_TO_CONTROLLER_LOG:GEN4_CONNECT_INT_LOG_PIC18F47Q83 null
578 1726315976703 GEN4_TO_CONTROLLER_LOG:GEN4_CONNECT_INT_LOG_PIC18F47Q83 Payload End
578 1726315976705 XXXX 1726315976705, Thread 578: com.Send returned false 
578 1726315976705 XXXX 1726315976705, Thread 578: execCommand: exception after writeSideChanel null

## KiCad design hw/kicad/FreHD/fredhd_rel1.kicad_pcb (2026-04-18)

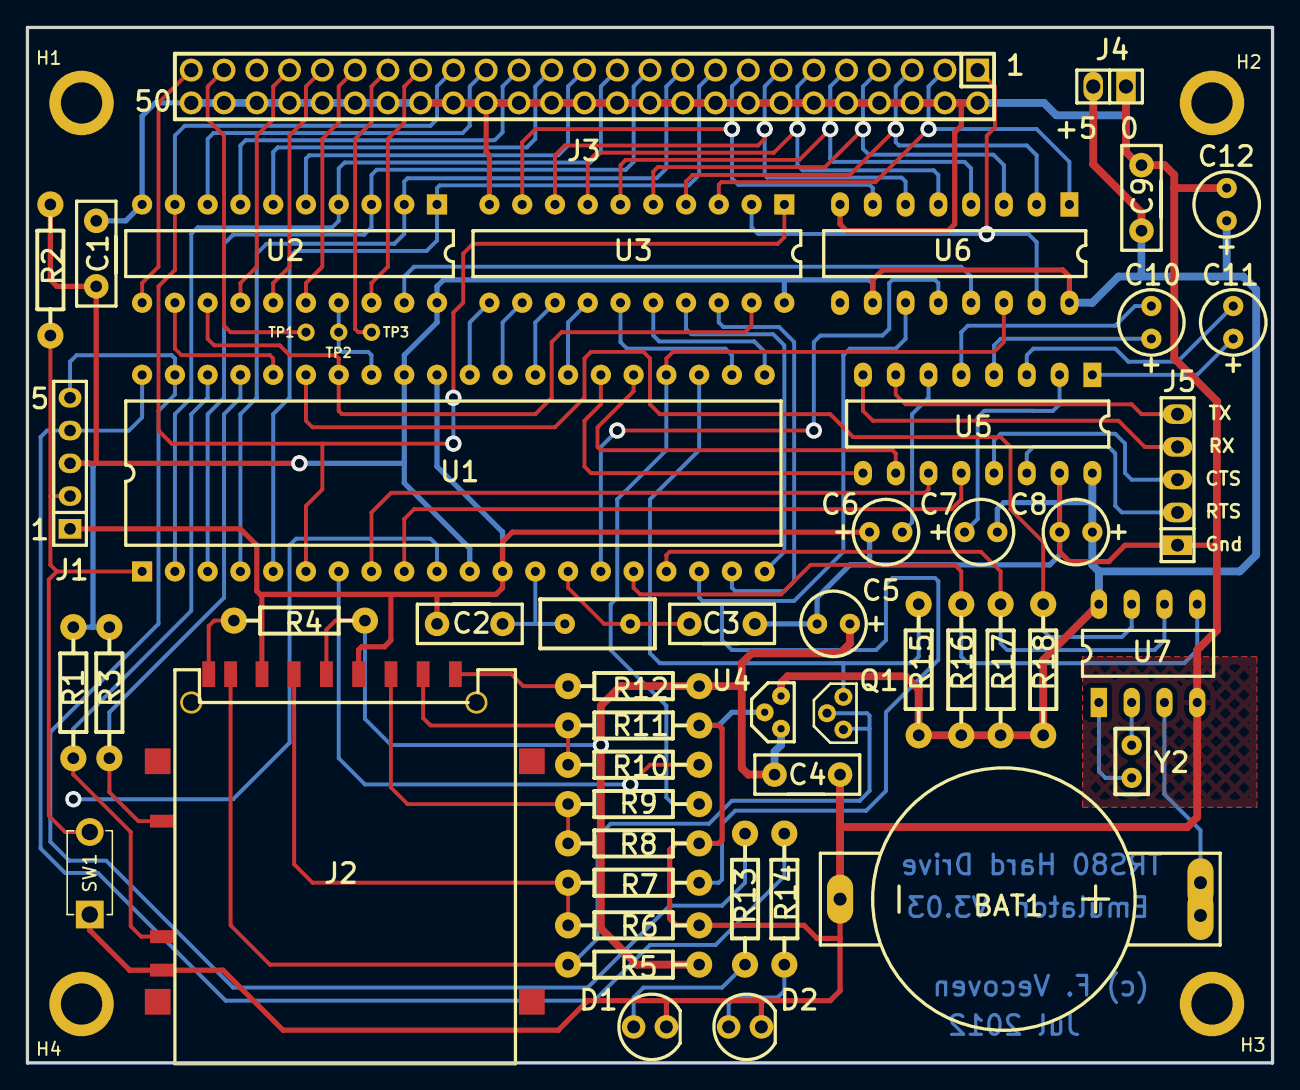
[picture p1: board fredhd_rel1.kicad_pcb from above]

Board: 2 copper layers, 96.5 x 80.3 mm, 56 parts (0 on the bottom side), 66 nets.

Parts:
BAT1: 3.3V; CR2032
C1, C4, C9: 100n; RAD-0.2
C2, C3: 22p; RAD-0.2
C5, C12: 10u; RB.1
C6, C7, C8, C10, C11: 1uF; RB.1
D1, D2: LED; LEDFRED
H1, H2, H3, H4: MountingHole; MountingHole_3.2mm_M3_DIN965_Pad
J1: CON5; SIP5FS
J2: SDCARD; SDCARD1
J3: CON50; IDC50F
J4: CON2; SIP2
J5: CON5; SIP5F
Q1: BS170; TO92-BS170
R1, R3: 1k; AXI-0.4
R2, R4, R5, R12, R15: 10k; AXI-0.4
R6, R8, R11, R13, R14: 330; AXI-0.4
R7, R9, R10: 220; AXI-0.4
R16, R17, R18: 4k7; AXI-0.4
SW1: SW_Push; PinHeader_1x02_P2.54mm_Vertical
TP1, TP2, TP3: Conn_01x01; PinHeader_1x01_P2.00mm_Vertical
U1: PIC18F4610; DIP40F
U2: GAL16V8; DIP20F
U3: 74HCT245; DIP20F
U4: LP2950-3.3; TO92-LP2950
U5: MAX232; DIP16F
U6: 74HC595; DIP16F
U7: DS1307; DIP8F
Y1: 10MHz; RAD0.2
Y2: 32.768kHz; RAD-0.1

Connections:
3V3: C4.1, C5.1, J2.4 (VDD), R4.2, R5.2, R12.2, U4.3 (Vout)
/A0: J3.17, U1.5 (RA3), U2.1 (IN_0/CLK)
/A1: J3.19, U1.4 (RA2), U2.2 (IN_1)
/A2: J3.21, U1.3 (RA1), U2.3 (IN_2)
/A3: J3.23, U1.2 (RA0), U2.4 (IN_3)
/A4: J3.25, U2.5 (IN_4)
/A5: J3.27, U2.6 (IN_5)
/A6: J3.29, U2.7 (IN_6)
/A7: J3.31, U2.8 (IN_7)
/BUS_INT_N: J3.39, U2.16 (IO_4)
/BUS_WAIT_N: J3.41, U2.15 (IO_3)
/CTS: U1.9 (RE1), U5.12 (R1out)
/D0: J3.1, U3.2 (A1), U6.15 (O0)
/D1: J3.3, U3.3 (A2), U6.1 (O1)
/D2: J3.5, U3.4 (A3), U6.2 (O2)
/D3: J3.7, U3.5 (A4), U6.3 (O3)
/D4: J3.9, U3.6 (A5), U6.4 (O4)
/D5: J3.11, U3.7 (A6), U6.5 (O5)
/D6: J3.13, U3.8 (A7), U6.6 (O6)
/D7: J3.15, U3.9 (A8), U6.7 (O7)
/DD0: U1.19 (RD0), U3.18 (B1)
/DD1: U1.20 (RD1), U3.17 (B2)
/DD2: U1.21 (RD2), U3.16 (B3)
/DD3: U1.22 (RD3), U3.15 (B4)
/DD4: U1.27 (RD4), U3.14 (B5)
/DD5: U1.28 (RD5), U3.13 (B6)
/DD6: U1.29 (RD6), U3.12 (B7)
/DD7: U1.30 (RD7), U3.11 (B8)
/EXTIOSEL_N: J3.43, U2.14 (IO_2)
/IORQ_N: J3.49, U2.11 (~IN_9/OE)
/LED0: J1.4, R14.2, U1.40 (RB7)
/LED1: J1.5, R13.2, U1.39 (RB6)
/M1_N: J3.47, TP1.1
/MCLR: J1.2, R2.2, SW1.2, U1.1 (MCLR)
/OSC1: C2.1, U1.13 (OSC1), Y1.1
/OSC2: C3.1, U1.14 (OSC2), Y1.2
/PIC_SEL_N: U1.34 (RB1), U2.13 (IO_1), U3.19 (~G)
/PIC_WAIT_N: U1.36 (RB3), U2.12 (IO_0)
/RD_N: J3.33, U1.6 (RA4), U2.9 (IN_8), U3.1 (DIR)
/RESET_N: J3.37, TP3.1
/RTC: R18.1, U1.35 (RB2), U7.7 (OUT)
/RTS: U1.8 (RE0), U5.11 (T1in)
/RX: U1.26 (RC7), U5.9 (R2out)
/SCL: R17.1, U1.17 (RC2), U7.6 (SCL)
/SDA: R16.1, U1.16 (RC1), U7.5 (SDA)
/SD_CD: J2.12 (CARD_DETECT), R3.2, U1.37 (RB4)
/SD_CLK_3V3: J2.5 (CLK/SCLK), R6.2, R7.1
/SD_CS_3V3: J2.1 (DAT3/CD/CS), R10.1, R11.2
/SD_CS_5V: R10.2, U1.7 (RA5)
/SD_IN_3V3: J2.2 (CMD/DI), R8.2, R9.1
/SD_WRPROT: J2.11 (WR_PROTECT), R1.2, U1.38 (RB5)
/SPARE1: TP2.1, U1.33 (RB0), U2.17 (IO_5)
/SPI_CLK: R7.2, U1.18 (RC3), U6.11 (SRCLK)
/SPI_SDI: Q1.3 (D), R15.1, U1.23 (RC4)
/SPI_SDI_3V3: J2.7 (DAT0/DO), Q1.1 (G), Q1.2 (S), R5.1
/SPI_SDO: R9.2, U1.24 (RC5), U6.14 (SER)
/STAT_CS: U1.15 (RC0), U6.12 (RCLK)
/STAT_OE_N: U2.19 (IO_7), U6.13 (E)
/TX: U1.25 (RC6), U5.10 (T2in)
/WR_N: J3.35, U2.18 (IO_6)
/oCTS: J5.3, U5.13 (R1in)
/oRTS: J5.2, U5.14 (T1out)
/oRX: J5.4, U5.8 (R2in)
/oTX: J5.5, U5.7 (T2out)
GND: BAT1.1 (+), C1.2, C2.2, C3.2, C4.2, C5.2, C6.1, C8.2, C9.2, C12.2, D1.K (2), D2.K (2), J1.1, J2.3 (VSS1), J2.6 (VSS2), J2.10 (GND_SW), J3.2, J3.4, J3.6, J3.8, J3.10, J3.12, J3.14, J3.16, J3.18, J3.20, J3.22, J3.24, J3.26, J3.28, J3.30, J3.32, J3.34, J3.36, J3.38, J3.40, J3.42, J3.44, J3.46, J3.48, J3.50, J4.1, J5.1, R6.1, R8.1, R11.1, SW1.1, U1.12 (VSS), U1.31 (VSS), U2.10 (GND), U3.10 (GND), U4.2 (GND), U5.15 (Gnd), U6.8 (GND), U7.4 (Gnd)
VCC: C1.1, C7.2, C8.1, C9.1, C12.1, J1.3, J4.2, R1.1, R2.1, R3.1, R15.2, R16.2, R17.2, R18.2, U1.11 (VDD), U1.32 (VDD), U2.20 (VCC), U3.20 (VCC), U4.1 (Vin), U5.16 (Vcc), U6.10 (~SRCLR), U6.16 (VCC), U7.8 (Vdd)

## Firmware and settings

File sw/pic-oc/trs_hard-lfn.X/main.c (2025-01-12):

/*
 * Copyright (C) 2013 Frederic Vecoven
 *
 * This file is part of trs_hard
 *
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
 * You should have received a copy of the GNU General Public License
 * along with this program. If not, see <http://www.gnu.org/licenses/>.
 */

#include "HardwareProfile.h"
#include "mcc_generated_files/system/system.h"
#include <string.h>
#include "integer.h"
#include "FatFS/ff.h"
#include "FatFS/diskio.h"
#include "trs_hard.h"
#include "trs_extra.h"
//#include "trs_uart.h"
#include "sw_i2c.h"
#include "ds1307.h"
#include "action.h"
#include "serial.h"
#include "led.h"
#include "bootloader.h"
#include "eeprom.h"
#include "crc.h"

const USHORT crc16_val __at(FLASH_CRC_ADDR) = THECRC;
const USHORT exit_boot __at(EEPROM_START_ADDRESS + EEPROM_CRC_ADDR) = THECRC;

/* Global variables */
#pragma udata fs_buffer
FATFS fs;
Drive state_d[TRS_HARD_MAXDRIVES];
FIL state_file2;
#if EXTRA_IM_SUPPORT
#if FF_USE_FASTSEEK
DWORD im_stbl[FAST_SEEK_LEN];
#endif
FIL im_file;
BYTE im_buf[0x80];
#endif
BYTE sector_buffer[MAX_SECTOR_SIZE];
#if EXTRA_IM_SUPPORT
image_t im[8];
#endif
#pragma udata extra_buffer
BYTE extra_buffer[EXTRA_SIZE];
#pragma udata
DIR state_dir;
FILINFO state_fno;
UCHAR state_dir_open;
UCHAR state_file2_open;
UCHAR fs_mounted;
UCHAR cur_unit;
UCHAR led_count;
led_t rled;
led_t gled;

__near UCHAR expected_addr;

__near BYTE action_flags;
__near BYTE action_type;
__near BYTE action_status;
__near UCHAR state_busy;
__near UCHAR state_status;
__near UCHAR state_present;
__near UCHAR state_control;
__near UCHAR state_error;
__near UCHAR state_seccnt;
__near UCHAR state_secnum;
__near USHORT state_cyl;
__near UCHAR state_drive;
__near UCHAR state_head;
__near UCHAR state_wp;
__near UCHAR state_command;
__near USHORT state_bytesdone;
__near UCHAR state_secsize;
__near USHORT state_secsize16;
__near UCHAR state_command2;
__near UCHAR state_error2;
__near USHORT state_size2;
__near UCHAR state_bytesdone2;
__near UCHAR state_romdone;
__near UCHAR state_rom;
__near UCHAR val_1F;
__near UCHAR data2_out, data2_out1;
__near UCHAR data2_stream;
__near UCHAR crc7;
__near USHORT crc16;
__near UCHAR foo;
__near UCHAR gled_val;

/* local prototypes */
void handle_interrupt_low(void);


/*
 * Interrupt handlers
 */

asm(" global handle_int2");
asm("psect intcode,class=CODE,space=0,reloc=2,abs,ovrld");
asm(" org  0x1000");
asm(" goto start");
asm(" org  0x1008");
asm(" goto handle_int2");
asm(" org  0x1018");
asm(" goto _handle_interrupt_low");

void __interrupt(low_priority) handle_interrupt_low(void)
{
    if(PIE3bits.TMR2IE && PIR3bits.TMR2IF) {
		PIR3bits.TMR2IF = 0;
		disk_timerproc();
		action_flags |= ACTION_TICK;
	}
    if(RTC_INT_IE && RTC_INT_IF) {
		RTC_INT_IF = 0;
		ds1307_int();
	}
    if(PIE4bits.U1TXIE && PIR4bits.U1TXIF) {
        //PIR4bits.U1TXIF = 0;
		serial_tx_int();
	}
    if(PIE4bits.U1RXIE && PIR4bits.U1RXIF) {
        //PIR4bits.U1RXIF = 0;
		serial_rx_int();
	}
}


void pic_init(void)
{
	UCHAR i;

	IVTLOCK = 0x55;
	IVTLOCK = 0xAA;
	IVTLOCKbits.IVTLOCKED = 0x00; // unlock IVT

	IVTBASEU = 0;
	IVTBASEH = 16;
	IVTBASEL = 8;

	IVTLOCK = 0x55;
	IVTLOCK = 0xAA;
	IVTLOCKbits.IVTLOCKED = 0x01; // lock IVT

    NVMCON1bits.WRERR = 0;

	/* SD Card */
	SD_CS_TRIS = OUTPUT_PIN;
	SD_WP_TRIS = INPUT_PIN;
	SD_CD_TRIS = INPUT_PIN;
	SPI_SCK_TRIS = OUTPUT_PIN;
	SPI_MISO_TRIS = INPUT_PIN;
	SPI_MOSI_TRIS = OUTPUT_PIN;
	SD_CS = 1;

	/* Status 74HC595 */
	STAT_CS_TRIS = OUTPUT_PIN;
	STAT_CS = 0;

	/* TRS80 and GAL */
//	ADCON1 = 0x0f;
	TRS_ADDR_TRIS |= 0x0F;
	TRS_WAIT_TRIS = OUTPUT_PIN;
	TRS_WAIT = 0;
	TRS_RD_N_TRIS = INPUT_PIN;
	GAL_INT_TRIS = INPUT_PIN;
	GAL_INT_IE = 1;
	GAL_INT_IP = 1;
	GAL_INT_EDGE = 0;	// interrupt on falling edge

	/* DS1307 interrupt */
	RTC_INT_TRIS = INPUT_PIN;
	RTC_INT_IE = 1;
	RTC_INT_IP = 0;
	RTC_INT_EDGE = 0;

	/* Debug LED */
	GLED_TRIS = OUTPUT_PIN;
	RLED_TRIS = OUTPUT_PIN;
	GLED = 0;
	RLED = 0;

	/* Timer 2 : ~200Hz */
//	OpenTimer2(TIMER_INT_ON & T2_PS_1_16 & T2_POST_1_16);
//	PR2 = 195;
	IPR3bits.TMR2IP = 0;

	/* Enable SPI */
	SPI1CON0 = 0x02;
	SPI1CON1 = 0x40;
	SPI1CON2 = 0x00;
#if 1 // 64MHz
	SPI1BAUD = 0x02; // fast clock
#else // 40MHz
	SPI1BAUD = 0x01; // fast clock
#endif
	SPI1CLK = 0x00;
	SPI1CON0bits.EN = 1;

	/* Interrupt priorities */
	INTCON0bits.IPEN = 1;

	/* globals init */
	val_1F = 0x1F;
	expected_addr = 0xff; // won't match any input
	action_flags = 0;
	fs_mounted = FS_NOT_MOUNTED;
	state_file2_open = 0;
	state_dir_open = 0;
	for (i = 0; i < TRS_HARD_MAXDRIVES; i++) {
		state_d[i].filename[0] = '\0';
	}
}


static void handle_card_insertion(void)
{
	FRESULT rc;
	BYTE retry;

	gled.val |= LED_FLASH;
	fs_mounted = FS_MOUNTED_ERROR;
#if UART_DEBUG
	usart_puts2("Card inserted!");
#endif
	retry = 3;
	while ((rc = disk_initialize(0)) != RES_OK && retry-- > 0);
	if (rc == RES_OK) {
#if UART_DEBUG
		usart_puts2("Card initialized!");
#endif
		rc = f_mount(&fs, "", 1);
		if (rc == FR_OK) {
			fs_mounted = FS_MOUNTED_OK;
#if UART_DEBUG
			usart_puts2("FAT mounted");
#endif
			rc = open_drives();
#if UART_DEBUG
			if (rc == FR_OK) {
				usart_puts2("Drives mounted");
			}
#endif
		}
	}
	if (fs_mounted == FS_MOUNTED_ERROR) {
#if UART_DEBUG
		usart_puts2("Card init failed.");
#endif
		rled.val = LED_FAST_BLINK;
	}

	// capture result
	state_error2 = rc;
}


static void handle_card_removal(void)
{
#if UART_DEBUG
	usart_puts2("Card removed!");
#endif
	close_drives();
	f_unmount("");
	fs_mounted = 0;
	rled.val = LED_OFF;
}


void main(void)
{
	SYSTEM_Initialize();
	pic_init();
	led_init();
    gled_val = 0;
	i2c_init();
	ds1307_init();
	trs_hard_init();
	usart_init();
	TMR2_Start();

	/* Set READY status */
	state_busy = 0;
	update_status(TRS_HARD_READY);

	/* Enable interrupts */
	INTCON0bits.GIE = 1;
	INTCON0bits.GIEL = 1;

	// assert wait trigger
	TRS_WAIT = 0;

	while (1) {

		/* DS1307 : reload time from chip */
		if (action_flags & ACTION_DS1307_RELOAD) {
			ds1307_read_time();
			action_flags &= ~ACTION_DS1307_RELOAD;
		}

		/* tick 200Hz */
		if (action_flags & ACTION_TICK) {
			action_flags &= ~ACTION_TICK;

			/* handle LEDs */
			led_update(&rled);
			gled.val |= gled_val;
			gled_val = 0;
			led_update(&gled);

			/* sync hard drive files */
			trs_sync();

			/* card insertion */
			if (card_present() && fs_mounted == FS_NOT_MOUNTED) {
				handle_card_insertion();
			}

			/* card removal */
			if (!card_present() && fs_mounted != FS_NOT_MOUNTED) {
				handle_card_removal();
			}
		}

		/* hard drive and extra functions actions */
		if (action_flags & ACTION_TRS) {
			action_flags &= ~ACTION_TRS;
			trs_action();
		}

#if 0
		/* UART */
		trs_uart();
#endif
	}
}

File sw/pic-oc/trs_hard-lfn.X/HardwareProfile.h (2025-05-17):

/*
 * Copyright (C) 2013 Frederic Vecoven
 *
 * This file is part of trs_hard
 *
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
 * You should have received a copy of the GNU General Public License
 * along with this program. If not, see <http://www.gnu.org/licenses/>.
 */

#ifndef HARDWARE_PROFILE_H
#define HARDWARE_PROFILE_H
	
#include <xc.h>
	
/** CLOCK FREQUENCY ********************************************/
#define GetSystemClock()		(40000000ul)      // Hz
#define GetInstructionClock()	(GetSystemClock()/4)
#define GetPeripheralClock()	GetInstructionClock()
   
/** I/O pin definitions ****************************************/
#define INPUT_PIN 		1
#define OUTPUT_PIN 		0

/* SD CARD */
#define SD_CS			LATAbits.LATA5		// SD chip select
#define SD_CS_TRIS		TRISAbits.TRISA5	// SD chip select TRIS
#define SPI_SCK_TRIS	TRISCbits.TRISC3	// SPI Clock TRIS
#define SPI_MISO_TRIS	TRISCbits.TRISC4	// SPI Master input/Slave output TRIS
#define SPI_MOSI_TRIS	TRISCbits.TRISC5	// SPI Master output/Slave input TRIS
/*
 * Card write-protect and card detect must be on the same port.
 * If not, adapt diskio.c
 */
#define SD_WP			PORTBbits.RB5		// Card Write Protect
#define SD_WP_TRIS		TRISBbits.TRISB5	// Card Write Protect TRIS
#define SD_WP_PIN		5
#define SD_CD			PORTBbits.RB4		// Card Detect
#define SD_CD_TRIS		TRISBbits.TRISB4	// Card Detect TRIS
#define SD_CD_PIN		4
#define SD_WP_CD_PORT	PORTB

/* STATUS REGISTER */
#define STAT_CS			LATCbits.LATC0		// STATUS LOAD
#define STAT_CS_TRIS	TRISCbits.TRISC0
   
/* TRS80 signals */
#define TRS_ADDR		PORTA				// low nibble is A[3..0] reversed!  RW is bit 4
#define TRS_ADDR_TRIS	TRISA
#define TRS_DATA_IN		PORTD
#define TRS_DATA_OUT	LATD
#define TRS_DATA_TRIS	TRISD
#define TRS_RD_N		PORTAbits.RA4		// 0=read 1=write
#define TRS_RD_N_TRIS	TRISAbits.TRISA4
#define TRS_WAIT		LATBbits.LATB0
#define TRS_WAIT_TRIS	TRISBbits.TRISB0
#define GAL_INT_IE		PIE6bits.INT1IE
#define GAL_INT_IP		IPR6bits.INT1IP
#define GAL_INT_IF		PIR6bits.INT1IF
#define GAL_INT_EDGE	INTCON0bits.INT1EDG
#define GAL_INT_TRIS	TRISBbits.TRISB1
#define GAL_INT			PORTBbits.RB1

/* DS1307 RTC */
#define SDA_LAT			LATCbits.LATC1
#define SDA_PIN			PORTCbits.RC1
#define SDA_TRIS		TRISCbits.TRISC1
#define SCL_LAT			LATCbits.LATC2
#define SCL_PIN			PORTCbits.RC2
#define SCL_TRIS		TRISCbits.TRISC2
#define RTC_INT_IE		PIE10bits.INT2IE
#define RTC_INT_IP		IPR10bits.INT2IP
#define RTC_INT_IF		PIR10bits.INT2IF
#define RTC_INT_EDGE	INTCON0bits.INT2EDG
#define RTC_INT_TRIS	TRISBbits.TRISB2
#define RTC_INT			PORTBbits.RB2

/* Serial Port */
#define TX_TRIS			TRISCbits.TRISC6
#define RX_TRIS			TRISCbits.TRISC7
#define RTS_TRIS		TRISEbits.TRISE0
#define RTS_LAT			LATEbits.LATE0
#define RTS_PIN			PORTEbits.RE0
#define CTS_TRIS		TRISEbits.TRISE1
#define CTS_LAT			LATEbits.LATE1
#define CTS_PIN			PORTEbits.RE1

/* LEDs */
#define GLED			LATBbits.LATB7		// green LED 
#define GLED_TRIS		TRISBbits.TRISB7	// green LED TRIS
#define RLED			LATBbits.LATB6		// red LED
#define RLED_TRIS		TRISBbits.TRISB6	// red LED TRIS

typedef enum {
	LED_OFF,
	LED_ON,
	LED_FAST_BLINK,
	LED_SLOW_BLINK
} led_state_t;
	

/* Spare pins */
#define SPARE1_TRIS		TRISBbits.TRISB3
#define SPARE2_TRIS		TRISEbits.TRISE2

/** USART SETTINGS *********************************************/
#define BAUD_RATE 57600

#endif

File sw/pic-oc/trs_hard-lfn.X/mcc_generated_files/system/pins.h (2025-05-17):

/**
 * Generated Pins header File
 * 
 * @file pins.h
 * 
 * @defgroup  pinsdriver Pins Driver
 * 
 * @brief This is generated driver header for pins. 
 *        This header file provides APIs for all pins selected in the GUI.
 *
 * @version Driver Version  3.1.0
*/

/*
© [2024] Microchip Technology Inc. and its subsidiaries.

    Subject to your compliance with these terms, you may use Microchip 
    software and any derivatives exclusively with Microchip products. 
    You are responsible for complying with 3rd party license terms  
    applicable to your use of 3rd party software (including open source  
    software) that may accompany Microchip software. SOFTWARE IS ?AS IS.? 
    NO WARRANTIES, WHETHER EXPRESS, IMPLIED OR STATUTORY, APPLY TO THIS 
    SOFTWARE, INCLUDING ANY IMPLIED WARRANTIES OF NON-INFRINGEMENT,  
    MERCHANTABILITY, OR FITNESS FOR A PARTICULAR PURPOSE. IN NO EVENT 
    WILL MICROCHIP BE LIABLE FOR ANY INDIRECT, SPECIAL, PUNITIVE, 
    INCIDENTAL OR CONSEQUENTIAL LOSS, DAMAGE, COST OR EXPENSE OF ANY 
    KIND WHATSOEVER RELATED TO THE SOFTWARE, HOWEVER CAUSED, EVEN IF 
    MICROCHIP HAS BEEN ADVISED OF THE POSSIBILITY OR THE DAMAGES ARE 
    FORESEEABLE. TO THE FULLEST EXTENT ALLOWED BY LAW, MICROCHIP?S 
    TOTAL LIABILITY ON ALL CLAIMS RELATED TO THE SOFTWARE WILL NOT 
    EXCEED AMOUNT OF FEES, IF ANY, YOU PAID DIRECTLY TO MICROCHIP FOR 
    THIS SOFTWARE.
*/

#ifndef PINS_H
#define PINS_H

#include <xc.h>

#define INPUT   1
#define OUTPUT  0

#define HIGH    1
#define LOW     0

#define ANALOG      1
#define DIGITAL     0

#define PULL_UP_ENABLED      1
#define PULL_UP_DISABLED     0

// get/set RA0 aliases
#define TRS_ADDR3_TRIS                 TRISAbits.TRISA0
#define TRS_ADDR3_LAT                  LATAbits.LATA0
#define TRS_ADDR3_PORT                 PORTAbits.RA0
#define TRS_ADDR3_WPU                  WPUAbits.WPUA0
#define TRS_ADDR3_OD                   ODCONAbits.ODCA0
#define TRS_ADDR3_ANS                  ANSELAbits.ANSELA0
#define TRS_ADDR3_SetHigh()            do { LATAbits.LATA0 = 1; } while(0)
#define TRS_ADDR3_SetLow()             do { LATAbits.LATA0 = 0; } while(0)
#define TRS_ADDR3_Toggle()             do { LATAbits.LATA0 = ~LATAbits.LATA0; } while(0)
#define TRS_ADDR3_GetValue()           PORTAbits.RA0
#define TRS_ADDR3_SetDigitalInput()    do { TRISAbits.TRISA0 = 1; } while(0)
#define TRS_ADDR3_SetDigitalOutput()   do { TRISAbits.TRISA0 = 0; } while(0)
#define TRS_ADDR3_SetPullup()          do { WPUAbits.WPUA0 = 1; } while(0)
#define TRS_ADDR3_ResetPullup()        do { WPUAbits.WPUA0 = 0; } while(0)
#define TRS_ADDR3_SetPushPull()        do { ODCONAbits.ODCA0 = 0; } while(0)
#define TRS_ADDR3_SetOpenDrain()       do { ODCONAbits.ODCA0 = 1; } while(0)
#define TRS_ADDR3_SetAnalogMode()      do { ANSELAbits.ANSELA0 = 1; } while(0)
#define TRS_ADDR3_SetDigitalMode()     do { ANSELAbits.ANSELA0 = 0; } while(0)
   
// get/set RA1 aliases
#define TRS_ADDR2_TRIS                 TRISAbits.TRISA1
#define TRS_ADDR2_LAT                  LATAbits.LATA1
#define TRS_ADDR2_PORT                 PORTAbits.RA1
#define TRS_ADDR2_WPU                  WPUAbits.WPUA1
#define TRS_ADDR2_OD                   ODCONAbits.ODCA1
#define TRS_ADDR2_ANS                  ANSELAbits.ANSELA1
#define TRS_ADDR2_SetHigh()            do { LATAbits.LATA1 = 1; } while(0)
#define TRS_ADDR2_SetLow()             do { LATAbits.LATA1 = 0; } while(0)
#define TRS_ADDR2_Toggle()             do { LATAbits.LATA1 = ~LATAbits.LATA1; } while(0)
#define TRS_ADDR2_GetValue()           PORTAbits.RA1
#define TRS_ADDR2_SetDigitalInput()    do { TRISAbits.TRISA1 = 1; } while(0)
#define TRS_ADDR2_SetDigitalOutput()   do { TRISAbits.TRISA1 = 0; } while(0)
#define TRS_ADDR2_SetPullup()          do { WPUAbits.WPUA1 = 1; } while(0)
#define TRS_ADDR2_ResetPullup()        do { WPUAbits.WPUA1 = 0; } while(0)
#define TRS_ADDR2_SetPushPull()        do { ODCONAbits.ODCA1 = 0; } while(0)
#define TRS_ADDR2_SetOpenDrain()       do { ODCONAbits.ODCA1 = 1; } while(0)
#define TRS_ADDR2_SetAnalogMode()      do { ANSELAbits.ANSELA1 = 1; } while(0)
#define TRS_ADDR2_SetDigitalMode()     do { ANSELAbits.ANSELA1 = 0; } while(0)
   
// get/set RA2 aliases
#define TRS_ADDR1_TRIS                 TRISAbits.TRISA2
#define TRS_ADDR1_LAT                  LATAbits.LATA2
#define TRS_ADDR1_PORT                 PORTAbits.RA2
#define TRS_ADDR1_WPU                  WPUAbits.WPUA2
#define TRS_ADDR1_OD                   ODCONAbits.ODCA2
#define TRS_ADDR1_ANS                  ANSELAbits.ANSELA2
#define TRS_ADDR1_SetHigh()            do { LATAbits.LATA2 = 1; } while(0)
#define TRS_ADDR1_SetLow()             do { LATAbits.LATA2 = 0; } while(0)
#define TRS_ADDR1_Toggle()             do { LATAbits.LATA2 = ~LATAbits.LATA2; } while(0)
#define TRS_ADDR1_GetValue()           PORTAbits.RA2
#define TRS_ADDR1_SetDigitalInput()    do { TRISAbits.TRISA2 = 1; } while(0)
#define TRS_ADDR1_SetDigitalOutput()   do { TRISAbits.TRISA2 = 0; } while(0)
#define TRS_ADDR1_SetPullup()          do { WPUAbits.WPUA2 = 1; } while(0)
#define TRS_ADDR1_ResetPullup()        do { WPUAbits.WPUA2 = 0; } while(0)
#define TRS_ADDR1_SetPushPull()        do { ODCONAbits.ODCA2 = 0; } while(0)
#define TRS_ADDR1_SetOpenDrain()       do { ODCONAbits.ODCA2 = 1; } while(0)
#define TRS_ADDR1_SetAnalogMode()      do { ANSELAbits.ANSELA2 = 1; } while(0)
#define TRS_ADDR1_SetDigitalMode()     do { ANSELAbits.ANSELA2 = 0; } while(0)
   
// get/set RA3 aliases
#define TRS_ADDR0_TRIS                 TRISAbits.TRISA3
#define TRS_ADDR0_LAT                  LATAbits.LATA3
#define TRS_ADDR0_PORT                 PORTAbits.RA3
#define TRS_ADDR0_WPU                  WPUAbits.WPUA3
#define TRS_ADDR0_OD                   ODCONAbits.ODCA3
#define TRS_ADDR0_ANS                  ANSELAbits.ANSELA3
#define TRS_ADDR0_SetHigh()            do { LATAbits.LATA3 = 1; } while(0)
#define TRS_ADDR0_SetLow()             do { LATAbits.LATA3 = 0; } while(0)
#define TRS_ADDR0_Toggle()             do { LATAbits.LATA3 = ~LATAbits.LATA3; } while(0)
#define TRS_ADDR0_GetValue()           PORTAbits.RA3
#define TRS_ADDR0_SetDigitalInput()    do { TRISAbits.TRISA3 = 1; } while(0)
#define TRS_ADDR0_SetDigitalOutput()   do { TRISAbits.TRISA3 = 0; } while(0)
#define TRS_ADDR0_SetPullup()          do { WPUAbits.WPUA3 = 1; } while(0)
#define TRS_ADDR0_ResetPullup()        do { WPUAbits.WPUA3 = 0; } while(0)
#define TRS_ADDR0_SetPushPull()        do { ODCONAbits.ODCA3 = 0; } while(0)
#define TRS_ADDR0_SetOpenDrain()       do { ODCONAbits.ODCA3 = 1; } while(0)
#define TRS_ADDR0_SetAnalogMode()      do { ANSELAbits.ANSELA3 = 1; } while(0)
#define TRS_ADDR0_SetDigitalMode()     do { ANSELAbits.ANSELA3 = 0; } while(0)
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

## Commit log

2024-08-25 Replaced mmc crc functions in c with assembly.
2024-08-28 Replaced mcc generated nvm drivers with application code copied from the drivers.
    [bootloader.c, main.c]
2024-08-28 Changed generate_crc script to generate a c header instead of assembly include.
2024-09-04 Removed mcc generated nvm driver code from bootflasher.
2024-09-14 Fixed LED blink bug.
2024-09-16 Fix for trsvid bug exposed after LED bugfix.
    [main.c]
2024-09-17 Synced with trsvid bugfix in original code. Not actually needed here though.
    [main.c]
2024-09-17 Moved PIC sourcecode pic folder.
    [simul.DSN]
2025-01-12 Corrected references for FAT FS fast seek option from _USE_FASTSEEK to FF_USE_FASTSEEK. Updated FAT FS to R0.15a with 1/9/25 patch. Updated version to 3.55.
    [io.c, main.c, trs_hard.c]
2025-05-17 Added versions of GAL and PIC firmwares.
    [simul.DSN]
2026-04-18 Added kicad files
    [fredhd_rel1-B_Cu.gbr, fredhd_rel1-B_Mask.gbr, fredhd_rel1-B_Paste.gbr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]

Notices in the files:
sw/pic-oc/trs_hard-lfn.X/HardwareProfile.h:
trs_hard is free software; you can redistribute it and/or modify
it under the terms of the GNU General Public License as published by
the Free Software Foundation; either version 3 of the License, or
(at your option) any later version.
